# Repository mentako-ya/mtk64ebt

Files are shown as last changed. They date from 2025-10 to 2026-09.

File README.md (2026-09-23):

## 目次

- [mtk64ebt](#mtk64ebt)
    - [トラックボール＆ロータリーエンコーダー付きBluetooth接続自作キーボード](#トラックボールロータリーエンコーダー付きbluetooth接続自作キーボード)
- [バッテリーに関する注意](#バッテリーに関する注意)
- [オンラインストア](#オンラインストア)
- [本体以外に必要なパーツとおすすめ商品](#本体以外に必要なパーツとおすすめ商品)
- [特徴](#特徴)
    - [親指操作トラックボール搭載](#親指操作トラックボール搭載)
        - [ベアリング仕様トラックボールケース対応](#ベアリング仕様トラックボールケース対応)
        - [ベアリング仕様トラックボールケースデータ](#ベアリング仕様トラックボールケースデータ)
    - [Alps alpine製低背エンコーダー搭載](#alps-alpine製低背エンコーダー搭載)
    - [MCU (Seeed Studio XIAO nRF52840)](#mcu-seeed-studio-xiao-nrf52840)
    - [フットスイッチ対応](#フットスイッチ対応)
    - [ZMK Studio 対応](#zmk-studio-対応)
    - [ドングル対応](#ドングル対応)
        - [ドングルにOLEDを取り付けて動作状況を表示できます](#ドングルにoledを取り付けて動作状況を表示できます)
    - [LED表示](#led表示)
        - [セントラル側のLEDで現在のレイヤーが確認できます](#セントラル側のledで現在のレイヤーが確認できます)
        - [LEDレンズ](#ledレンズ)
- [フットスイッチ拡張基板](#フットスイッチ拡張基板)
    - [フットスイッチ無線化モジュール（概要）](#フットスイッチ無線化モジュール概要)
    - [本体基板キットを使用したカスタマイズが可能です](#本体基板キットを使用したカスタマイズが可能です)
- [使用方法](#使用方法)
    - [モジュール間接続](#モジュール間接続)
    - [USB接続](#usb接続)
    - [Bluetooth接続](#bluetooth接続)
    - [ロープロファイル化](#ロープロファイル化)
    - [フットスイッチ拡張キット](#フットスイッチ拡張キット)
    - [フットスイッチ無線化モジュール](#フットスイッチ無線化モジュール)
- [ファームウェア](#ファームウェア)
    - [Rev4 と Rev3 のハードウェア仕様比較](#rev4-と-rev3-のハードウェア仕様比較)
    - [Rev4用ファームウェア一覧](#rev4用ファームウェア一覧)
    - [Rev3用ファームウェア一覧](#rev3用ファームウェア一覧)
    - [ファームウェア書き込み手順](#ファームウェア書き込み手順)
- [ファームウェアのブランチ構成について](#ファームウェアのブランチ構成について)
- [キーマッピング変更](#キーマッピング変更)
    - [ZMK Studioでキーマッピング変更](#zmk-studioでキーマッピング変更)
        - [ブラウザ版 ZMK Studio](#ブラウザ版-zmk-studio)
        - [アプリ版 ZMK Studio](#アプリ版-zmk-studio)
    - [KeymapEditorでキーマッピング変更](#keymapeditorでキーマッピング変更)
- [トラックボール設定](#トラックボール設定)
    - [トラックボール機能のリアルタイム制御 (Rev4 / Rev3)](#トラックボール機能のリアルタイム制御-rev4--rev3)
    - [トラックボール設定変更](#トラックボール設定変更)
        - [自動マウスレイヤー（Layer 6）の設定変更](#自動マウスレイヤーlayer-6の設定変更)
        - [トラックボール感度（CPI）の初期値調整](#トラックボール感度cpiの初期値調整)
- [ケースデータ](#ケースデータ)

# mtk64ebt
<br>

## トラックボール＆ロータリーエンコーダー付きBluetooth接続自作キーボード

mtk64ebtは、親指操作トラックボールとロータリーエンコーダーを搭載した完全ワイヤレス接続分割式キーボードです。

トラックボールとエンコーダーの組み合わせにより、直感的で効率的な操作を実現します。

ワイヤレス接続によりケーブルの煩わしさから解放され、どこへでも快適に持ち運べます。

標準的な６０％キーボード相当のキー数 ＋ フルサイズのキースイッチ ＋ フットスイッチ拡張で、一般的なキーボードからの移行コストを抑え、フルキーボード以上の操作性を実現します。

はんだ付けとケースの組み立てが完了している半完成キットです。キースイッチとキーキャップ、トラックボールを取り付けるだけで、すぐに使用を開始することができます。

## バッテリーに関する注意

> [!CAUTION]
> バッテリー駆動用に[リチウムポリマーバッテリー](https://amzn.asia/d/1ivvf2l)を使用します。
> バッテリーの取り扱いを誤った場合や、製造上の不具合により、破裂や発火の恐れがあります。
> 組み立ての際に動作確認は行っていますが、絶対に安全であることを保証するものではありません。
> バッテリーは使用者の責任において使用してください。
> バッテリー、本体基板、その他構成部品を含め、本製品による事故および不利益損害についての一切の責任は使用者にあり、当方が責任を持つものではありません。

* バッテリー駆動時および、充電時は本体側面のバッテリー駆動用スイッチをONにしてください。
* バッテリー不使用時はバッテリー駆動用スイッチをOFFにしてください。
* 充電中は、発火・破裂しても被害のない場所を選定し、周囲に延焼するものを置かないようにしてください。また充電中はその場を離れることなく常に Li-Po の充電状態を監視してください。
* バッテリーの取り扱いや製造上の不具合について懸念がある場合や、ご自身の責任で使用できない場合、キーボードからバッテリーを取り外してご使用ください。
USB端子からの給電のみでキーボードを使用できます。

## オンラインストア
https://mentako-ya.myshopify.com

## 本体以外に必要なパーツとおすすめ商品

キーキャップMX互換: [CORSAIR PBT DOUBLE-SHOT 交換用カラーキーキャップセット - 日本語108キー, Arctic White - CH-9911040-JP](https://amzn.asia/d/1FShFiO)

キーキャップChocV2: [XVX ロープロファイル PBT キーキャップ](https://amzn.asia/d/7V1A6T4)

キーキャップChocV1: [Chocfox CFX keycap](https://chosfox.com/products/chocfox-cfx-choc-keycaps?bg_ref=3KtshOemT6)

トラックボール: [ぺリックス PERIPRO-303WH 34mm](https://amzn.asia/d/1paUF5C)

USB Type-cケーブル: https://amzn.asia/d/h8pfZIJ

クッションゴム: [ダイソー クッションゴム透明](https://jp.daisonet.com/products/4903409153222)

T5ドライバー(メンテナンス用): [アネックス(ANEX) ドライバー ヘクスローブ T4x50](https://amzn.asia/d/8RFoACS)

## 特徴

### 親指操作トラックボール搭載

キー操作時のトラックボールへの干渉を避けるため、トラックボールの取り付け位置は極力低くオフセットされています

トラックボールケース底面もフラット形状にして、全体の高さを抑えました。

<br>

Rev4ではトラックボールセンサーに**PixArt PAW3222**を採用しました。
Rev3以前のPMW3610と比較して、より低消費電力で高感度と高ポーリングレートを実現しています。

センサー取り付け角度を20度上向きに設定したことで、テンティングなしでも快適にトラックボールを操作することができます。
また、Rev4ではキー操作によるリアルタイムなCPI動的調整（16段階・不揮発性メモリ保存）に対応しています。

<br>

#### トラックボール機能のリアルタイム調整とキーマップ (Rev4)

トラックボールの各種機能（CPI感度調整、Auto Mouse Layer、スクロール反転）は、**レイヤー 1（精密モード）の右手最右列**のキー操作によって、ファームウェアの再書き込みなしでリアルタイムに切り替え・調整が可能です。設定内容は不揮発性メモリ（NVS）に自動保存され、電源オフ後も保持されます。

| 段 | キーコード | 機能 | 説明 |
| :--- | :--- | :--- | :--- |
| **右手最右列 2段目 (ROW 2)** | `&scrl_inv_tog` | スクロール反転切替 | レイヤー3（スクロール）での上下方向（通常 ⇔ 反転）をトグル |
| **右手最右列 3段目 (ROW 3)** | `&aml_tog` | Auto Mouse Layer切替 | ボール操作時の自動マウスレイヤー（レイヤー6）遷移の ON ⇔ OFF |
| **右手最右列 4段目 (ROW 4)** | `&cpi_inc` | CPI 感度UP | トラックボール解像度を1段階上げる（全16段階: 608〜4826 CPI） |
| **右手最右列 最下段 (ROW 5)** | `&cpi_dec` | CPI 感度DOWN | トラックボール解像度を1段階下げる |

※通常マウスモードであるレイヤー 2（MSE）では、誤入力防止のため最右列はすべて透過（`&trans`）となっています。<br>
※OLEDディスプレイ付きドングルでは、現在のCPI数値や機能のON/OFF（下線表示）がリアルタイムに表示されます。詳細な設定方法や仕様については[トラックボール機能のリアルタイム制御 (Rev4)](#トラックボール機能のリアルタイム制御-rev4)を参照してください。

#### ベアリング仕様トラックボールケース対応
トラックボール支持球をベアリングに置き換えるケースデータを公開しています。
ご自身でプリントしてベアリング仕様に変更可能です。



ケースの他に、ベアリング(内径 1.5mm 外径 4mm 幅 2mmのシールドタイプ)とM1.4のネジが必要です。
* ベアリング : [ミネベアミスミ DDL-415ZZ](https://amzn.asia/d/fXq8wOI)
* ネジ : [M1.4-0.3 6mm](https://amzn.asia/d/c3SDJWJ)

#### ベアリング仕様トラックボールケースデータ
[mtk64ebt_rev3_ballBearingCase_RH.3mf](casedata/rev3/mtk64ebt_rev3_ballBearingCase_RH.3mf)<br>[mtk64ebt_rev3_bodyBallBeringBottmn_RH.3mf](casedata/rev3/mtk64ebt_rev3_bodyBallBeringBottmn_RH.3mf)

<br>

### Alps alpine製低背エンコーダー搭載

30クリックの回転操作とプッシュ操作による、直感的な操作が可能です。
一般的なエンコーダーと比較して、クリックトルク、プッシュトルク共に軽い操作感です。

<br>

#### Choc V1、[V2（固定ピンなしモデル）](https://ja.aliexpress.com/item/1005007361067887.html)、およびMX互換キースイッチを全てのキーに取り付けることが可能です

<br>

<br>

親指部分のみをロープロファイル化することも可能です。

追加の親指キースイッチは、操作性を向上させるため、さらに一段低くオフセットされています。

<br>

### MCU (Seeed Studio XIAO nRF52840)

[Seeed Studio XIAO nRF52840](https://jp.seeedstudio.com/Seeed-XIAO-BLE-nRF52840-p-5201.html)を使用しており、無線接続の自作キーボードで課題となる技適対応もクリアしています。

技術基準適合証明番号：[211-220207](https://www.tele.soumu.go.jp/giteki/SearchServlet?pageID=jk01&NUM_TYPE=1&NUM=211-220207)

<br>

光学式センサーに **PAW3222** を採用しており、各接続モード（ESBドングル接続、Bluetooth接続、USB有線接続）におけるポーリングレートの実測値と理論値は以下の通りです。

#### ESB（ドングル）接続時
- **理論値**：最大1000Hz (1ms)
- **実測値**：平均約980Hz / 最大984Hz
- 専用ドングルと超高速ワイヤレスプロトコル **ESB (Enhanced ShockBurst)** を使用することで、完全ワイヤレスでありながら有線接続と同等の超低遅延・高ポーリングレートを実現し、トラックボールの追従性が飛躍的に向上します。

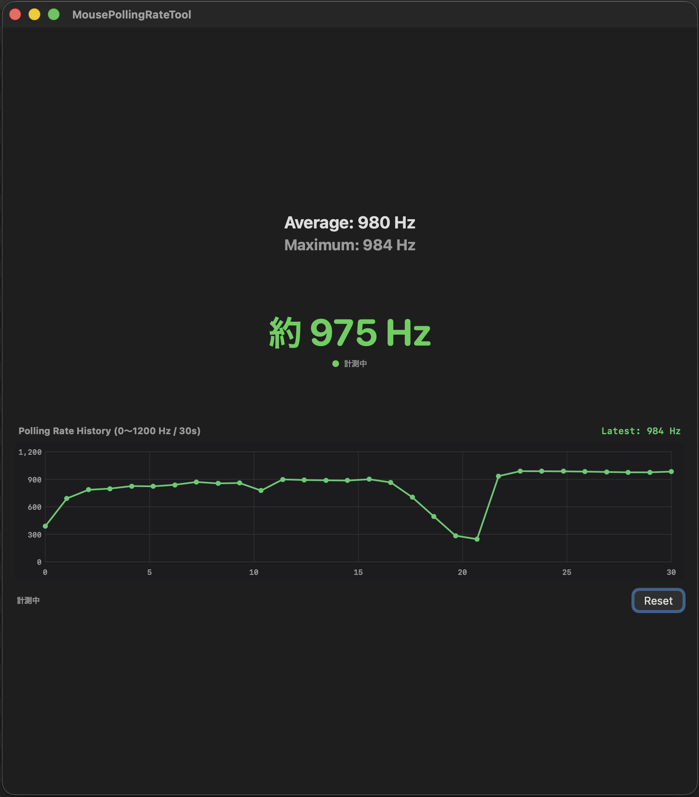
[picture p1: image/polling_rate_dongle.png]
<br>

#### Bluetooth（BLE）接続時
- **理論値**：最大約133Hz（BLE規格の最小接続インターバル 7.5ms 換算）
- **実測値**：平均約109Hz / 最大130Hz
- 一般的なオフィスワークや日常的なPC操作には十分滑らかに使用することが可能です。

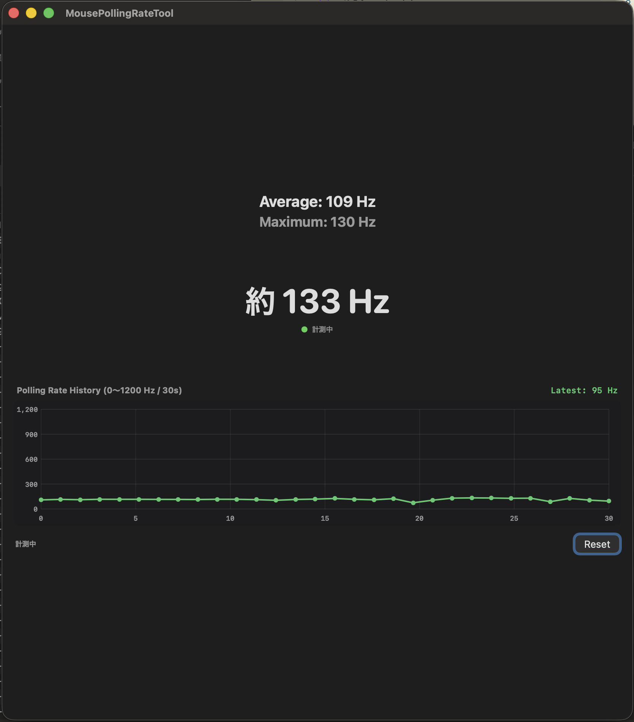
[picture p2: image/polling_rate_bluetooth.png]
<br>

#### USB（有線）接続時
- **理論値**：最大1000Hz (1ms)
- **実測値**：平均約979Hz / 最大984Hz
- ゲーミングマウスと同等の極めて高いポーリングレートを発揮し、高リフレッシュレートモニター環境でも吸い付くような滑らかで精密なトラックボール操作が可能です。
- 有線接続時もトラックボール搭載側（右手側等）のみUSB接続となり、反対側（左手側）は無線接続となるため、PCとの間はUSBケーブル1本のみで配線できます（左右間接続用のTRRSケーブルは使用しません）。

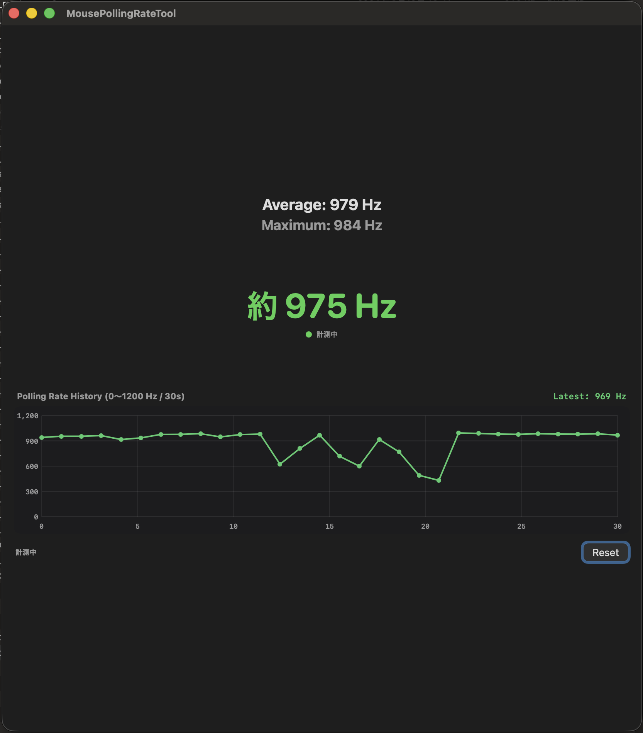
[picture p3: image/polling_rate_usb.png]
<br>

※ ポーリングレートの計測には、macOS向け計測ツール [MousePollingRateTool](https://github.com/mentako-ya/MousePollingRateTool) を使用しています。

### フットスイッチ対応
[市販のUSBフットスイッチ](https://amzn.asia/d/h7wMR24)の基板を付属のフットスイッチ拡張基板に差し替えて、mtk64の拡張無線フットスイッチとして使用可能です。

付属のフットスイッチ無線化モジュールを使用することで、フットスイッチも含めた完全ワイヤレス構成に対応します。

フットスイッチ拡張基板およびフットスイッチ無線化モジュールは、ご自身ではんだ付けと組み立てが必要なキットです。詳細は[フットスイッチ拡張基板](#フットスイッチ拡張基板)および[フットスイッチ無線化モジュール](#フットスイッチ無線化モジュール)を参照してください。

<br>

### ZMK Studio 対応

[ZMK Studio](#zmk-studioでキーマッピング変更)を使用して、キーマッピングを簡単に変更することができます。

<br>

### ESBを使用したドングル対応

[Seeed Studio XIAO BLE](https://jp.seeedstudio.com/Seeed-XIAO-BLE-nRF52840-p-5201.html) を専用ドングルとして使用することで、左右のキーボードは完全無線のまま、Nordic独自の超高速ワイヤレスプロトコル **ESB (Enhanced ShockBurst)** による超低遅延通信を行います。

完全ワイヤレスでありながら、USB直接接続と同等の **1000Hz (1ms)** に近いポーリングレートを実現し、トラックボールの追従性が飛躍的に向上します。（※Rev3ではBLEドングルによる約110~220Hz動作）

- **理論値**：1000Hz (1ms)
- **実測値**：平均約980Hz / 最大984Hz

<br>

<br>

#### ドングルにOLEDを取り付けて動作状況を表示できます

[0.96インチ 128×64ドットOLED(SSD1306)](https://akizukidenshi.com/catalog/g/g112031/)のGND,VCC,SCL,SDA を[XiaoBLEの GND,3v3,D10,D9 ](https://files.seeedstudio.com/wiki/XIAO-BLE/pinout2.png)に結線してください。

OLEDのピンヘッダ位置とXiaoBLEの端子位置を合わせてあるので、配線なしでピンヘッダで直付も可能です。

注：リセットスイッチは押せないので、リセットする際はXiaoBLE背面のRST端子とGND端子を短絡してください。

<br>
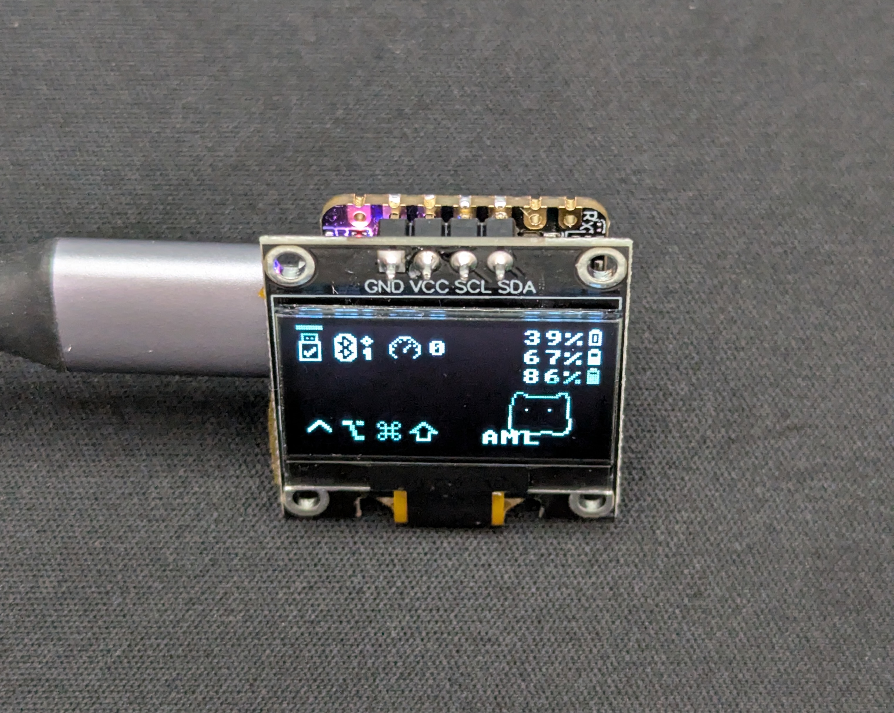
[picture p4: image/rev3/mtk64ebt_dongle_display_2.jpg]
<br>

##### OLEDディスプレイ画面の表示内容

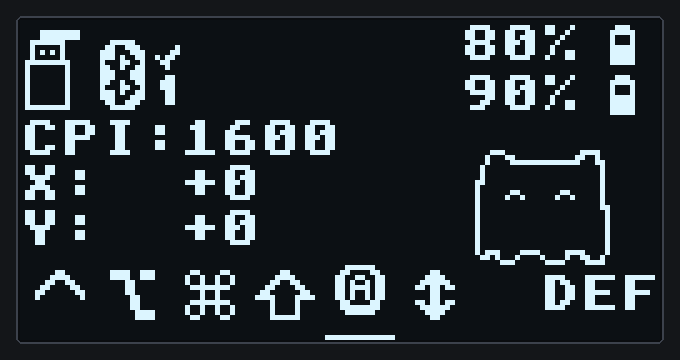
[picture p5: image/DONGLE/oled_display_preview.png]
<br>

| 領域 / アイコン | 表示内容 | 説明 |
| :--- | :--- | :--- |
| **左上 (出力状態)** | 🔌 USB / 📶 Bluetooth (1〜5) | 接続モード、選択中のBTプロファイル番号、接続状態（✓）を表示。現在選択されている出力の上部にバーが表示されます。 |
| **右上 (バッテリー)** | 🔋 L: 80% / R: 90% | 左右ペリフェラルのバッテリー残量（%）と電池アイコンをリアルタイム表示。 |
| **左中 (トラックボール)** | `CPI:1600`<br>`X:  +0`<br>`Y:  +0` | 現在のCPI解像度およびトラックボールのX/Y累積移動量をリアルタイム表示。 |
| **右中 (マスコット)** | めんたこ | 打鍵速度に連動してアニメーション。 |
| **左下 (モディファイア)** | `^` `⌥` `⌘` `⇧` | 現在押下中のモディファイアキー（Ctrl, Opt, Cmd, Shift）に下線（`_`）が表示されます。 |
| **中下 (ポインティング機能)** | 🎱 (A) Automouse<br>↕️ Scroll反転 | **Automouse**: 有効時に下線（`_`）が表示されます。<br>**Scroll反転**: スクロール反転有効時に下線（`_`）が表示されます。 |
| **右下 (レイヤー)** | `DEF`, `SNP`, `MSE` ... | 現在アクティブな最上位レイヤー名（`DEF`, `SNP`, `MSE`, `SCR`, `L4`, `L5`, `AML` 等）が右端に表示されます。 |

### LED表示

#### セントラル側のLEDで現在のレイヤーが確認できます
```
レイヤー０ ⚫️Black（無点灯）
レイヤー１ 🟣Magenta トラックボール精密モード
レイヤー２ 🔵Cyan    トラックボールモード
レイヤー３ 🟡Yellow  スクロールモード
レイヤー４ 🟢Green
レイヤー５ 🔵Blue
レイヤー６ ⚪️White   自動マウスレイヤー
```

#### LEDレンズ
インジケーターLEDにレンズを装着することで高い視認性を実現し、バッテリー残量や接続状態、レイヤー切り替えがわかりやすくなりました。

<br>

## フットスイッチ拡張基板

[市販のUSBフットスイッチ](https://amzn.asia/d/h7wMR24)の基板を付属のフットスイッチ拡張基板に差し替えてmtk64のフットスイッチとして使用可能です。

フットスイッチはmtk64の一部として機能するので、レイヤー切り替えやカスタムキーなどキーボード固有の操作が可能です。


<br>
<br>  

### フットスイッチ無線化モジュール（概要）
付属のフットスイッチ無線化モジュールにより完全無線接続のフットスイッチが完成します。

<br>

#### 本体基板キットを使用したカスタマイズが可能です

作例：左ボール 右エンコーダ ドングル OLED
（ファームウェア、ケースデータは各セクションを参照）
<br>

## 使用方法

## モジュール間接続

mtk64ebtは、右手モジュールがセントラルモジュールとして動作します。左手モジュールとフットスイッチは右手モジュールに自動的にペアリングされます。

各モジュールのLEDの色と接続状態については、[こちら](https://github.com/mentako-ya/zmk-rgbled-widget/blob/main/README.md)を参照してください。LEDの色によって接続状態が視覚的に確認できるため、接続状況を簡単に把握することができます。

各モジュール間の接続ができない場合は、ファームウェア書き込み手順に従って、各モジュールの接続をリセットしてください。接続の問題を解決して再度正常に動作させることができます。

## USB接続

右手モジュール（セントラルモジュール）は、PCとUSBで有線接続可能です。USB接続時、セントラルモジュールはPCとの通信を行いながら、充電も行います。

左手モジュールやフットスイッチ無線化モジュール（ペリフェラルモジュール）は、USB接続時に充電のみを行います。これらのモジュールは、操作に必要な通信をすべて無線接続でセントラルモジュールと行います。

> [!CAUTION]
> Rev.2以前の右手モジュールと左手モジュールにある3.5mmジャックはフットスイッチ拡張キットを有線接続するための端子です。
> 左右間の有線接続用ではありません。
> 故障の原因となるので、左右のキーボードをTRSケーブルで接続しないでください。

## Bluetooth接続

レイヤー1の「ESC」「1」〜「5」キーを使用して、最大６か所のBluetooth接続先を切り替えることができます。



接続後にキーボードが動作しない場合は、リセットボタンを押下して再接続を試みてください。

## ロープロファイル化

Choc V1、V2を使用する場合、トッププレート固定用ネジ(T5 8mm)を外してトッププレートを取り除き、付属の6mmねじに付け替えます。ネジの交換にはT5ドライバーを使用します。

## フットスイッチ拡張キット

フットスイッチ拡張キットはご自身で市販のフットスイッチにキットの基板を組み込み、はんだ付けをするキットです。

フットスイッチの作成方法は[こちらのビルドムービー](https://youtu.be/NavGAliALVc?si=JpO-xi0RZznjVi4-)をご覧ください。

フットスイッチの接続は3.5mm４極のTRRS端子を使用しますが、有線でフットスイッチを接続する場合（30cm以上のケーブル長が必要な場合）、市販のTRRSケーブルは線が細すぎるので使用できません。

TRRS端子とAWG28~26以上（番号が小さい方が太いです）のケーブルを組み合わせて自作します。

[遊舎工房自作ケーブルキット](https://shop.yushakobo.jp/products/self-made-cable?_pos=1&_sid=79305908f&_ss=r&variant=39623339737249)

[AWG26 4Cシールドケーブル](https://shop.oyaide.com/products/mogami_2893.html)

配線の色は使用するケーブルのメーカーによって異なります。
４極プラグの端子側とフットスイッチ拡張キット側の結線は下図を参照してください。

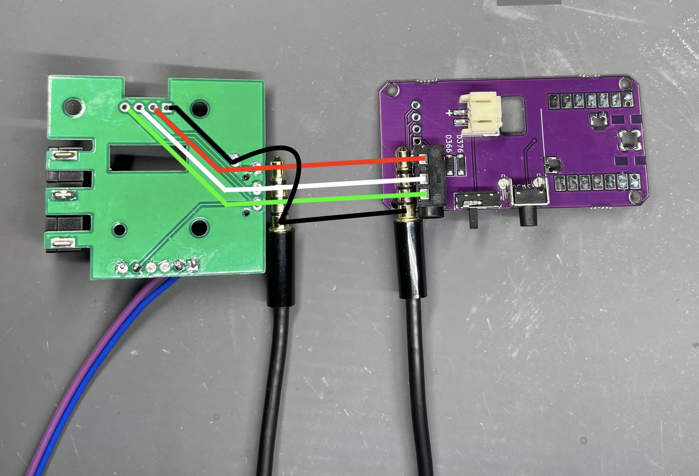
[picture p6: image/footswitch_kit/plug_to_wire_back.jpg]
<br>
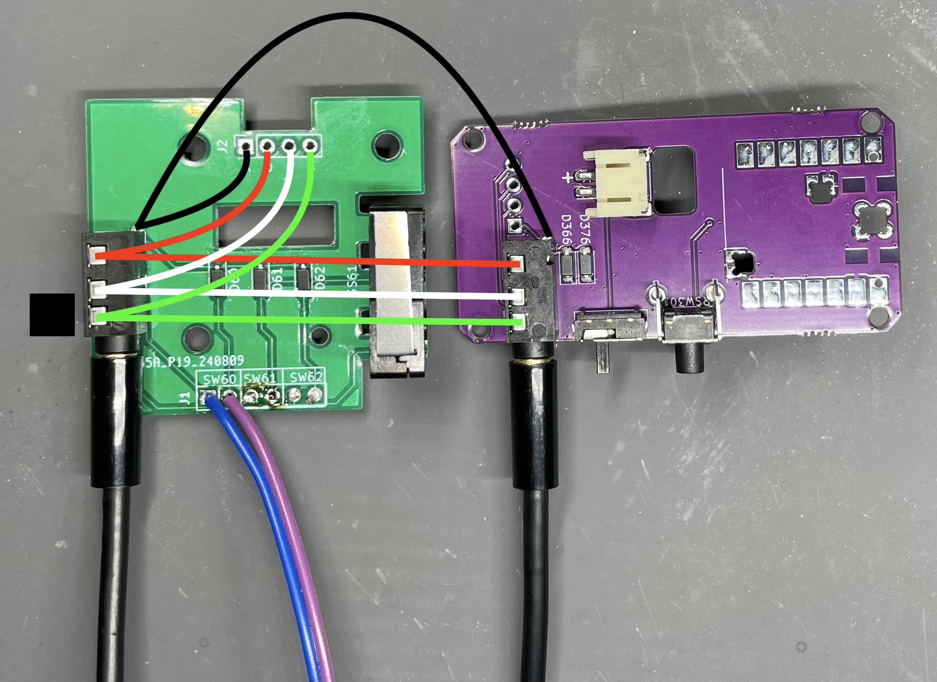
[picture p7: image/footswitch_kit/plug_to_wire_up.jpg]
<br>
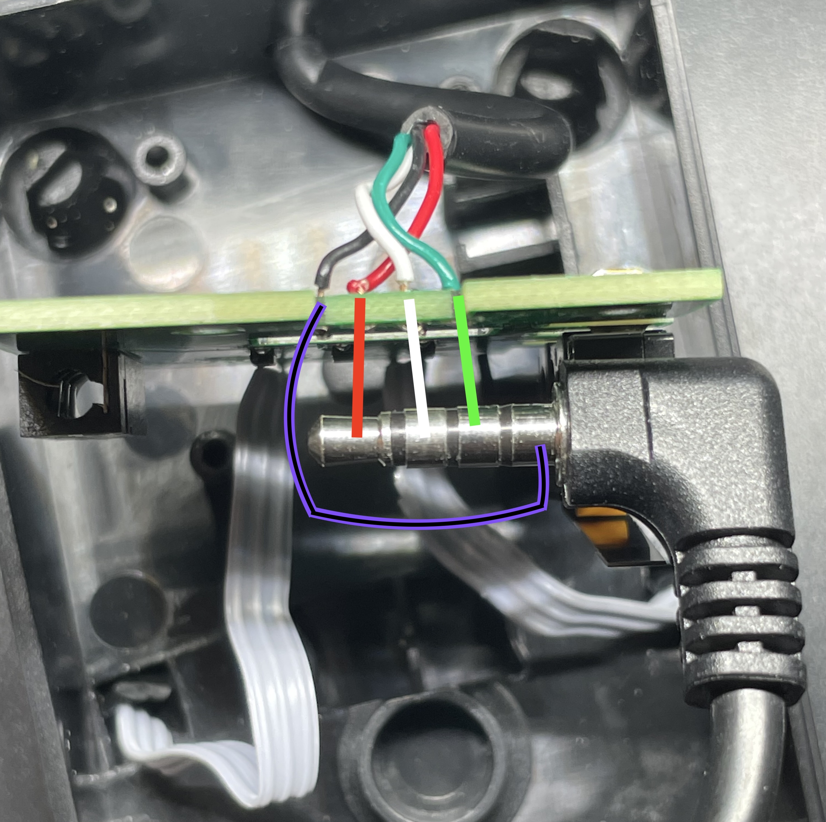
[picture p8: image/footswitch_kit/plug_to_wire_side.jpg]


## フットスイッチ無線化モジュール

フットスイッチ無線化モジュールを使用する場合、[Seeed Studio XIAO nRF52840](https://jp.seeedstudio.com/Seeed-XIAO-BLE-nRF52840-p-5201.html)、[リチウムポリマーバッテリー 902030 PH2.0プラグ付き](https://ja.aliexpress.com/item/1005006838195720.html)、[ケース（ご自身で3Dプリント）](casedata/rev3/mtk64ebt_rev3_footmodule_case.3mf) が別途必要です。

フットスイッチ拡張キットをフットスイッチ無線化モジュールに接続して、mtk64ebtに無線接続します。

フットスイッチキットとフットスイッチ無線化モジュールを接続する場合、フットスイッチ側の線を極力短くするのがオススメです。

写真は[こちらの４極3.5mm端子付きケーブル](https://www.digikey.jp/ja/products/detail/assmann-wsw-components/A-AV-02-45-28-183-S2/16906692)を15cmにカットして使用しています。


 

## ファームウェア

### Rev4 と Rev3 のハードウェア仕様比較

Rev4 と Rev3 では、搭載されているトラックボールセンサーの型番および CPI の調整ステップ数が異なりますが、ファームウェア機能としてはどちらも最新の仕様（ESB 1000Hz 超低遅延通信、リアルタイム設定制御、ZMK Studio 完全対応、ドングル OLED 連携）を共通してサポートしています。

| 比較項目 | Rev4（最新） | Rev3 |
| :--- | :--- | :--- |
| **トラックボールセンサー** | **PixArt PAW3222** | **PixArt PMW3610** |
| **CPI 調整範囲** | **16段階**（608 〜 4826 CPI） | **15段階**（200 〜 3200 CPI） |
| **PC / 親機間通信** | **Bluetooth (133Hz BLE Split)** または<br>**Nordic ESB (1000Hz 超低遅延)** | **Bluetooth (133Hz BLE Split)** または<br>**Nordic ESB (250Hz 超低遅延)** |
| **リアルタイム設定制御** | CPI感度調整 / Auto Mouse Layer / スクロール反転 | CPI感度調整 / Auto Mouse Layer / スクロール反転 |
| **設定の不揮発性保存 (NVS)** | 対応（電源OFF・電池交換後も保持） | 対応（電源OFF・電池交換後も保持） |
| **ZMK Studio** | 完全対応（リアルタイムキーマップ変更） | 完全対応（リアルタイムキーマップ変更） |
| **ドングル OLED 連携** | CPI値 / AML状態 / スクロール反転 / 電池残量 | CPI値 / AML状態 / スクロール反転 / 電池残量 |

> [!IMPORTANT]
> 搭載されているトラックボールセンサー（PAW3222 と PMW3610）のドライバが異なるため、**Rev4 と Rev3 でファームウェアのバイナリ互換性はありません**。
> お手持ちのキーボードのリビジョンに合致したファームウェアおよび対応ブランチをご使用ください。

---

### Rev4用ファームウェア一覧

本リポジトリでは、接続方式に応じてファームウェアを分離・最適化して提供しています。

#### 1. Bluetooth 接続（BLE Split / ドングル不要）構成【デフォルトブランチ: [`right_left_rev4`](https://github.com/mentako-ya/zmk-config-mtk64/tree/right_left_rev4)】

ドングルを使わず、右手（Central）と PC を Bluetooth でペアリングし、左手・フットスイッチとも安定した BLE Split 通信を行う標準構成です。
本リポジトリの [`firmware/rev4/`](firmware/rev4/) ディレクトリより最新版をダウンロードいただけます。

| No | 構成名 | パッケージ名 (ZIP) | 含まれるファームウェア (.uf2) |
| :--- | :--- | :--- | :--- |
| 1 | **左右構成（右ボール/左エンコーダー）** | [mtk64ebt_Right_Left.zip](firmware/rev4/mtk64ebt_Right_Left.zip) | `mtk64_R.uf2`, `mtk64_L.uf2`, `settings_reset.uf2` |
| 2 | **左右構成（左ボール/右エンコーダー）** | [mtk64ebt_Right_Left_leftball.zip](firmware/rev4/mtk64ebt_Right_Left_leftball.zip) | `mtk64_R_leftball.uf2`, `mtk64_L_leftball.uf2`, `settings_reset.uf2` |
| 3 | **左右＋フットスイッチ（右ボール/左エンコーダー）** | [mtk64ebt_Right_Left_Foot.zip](firmware/rev4/mtk64ebt_Right_Left_Foot.zip) | `mtk64_R.uf2`, `mtk64_L.uf2`, `mtk64_FOOT.uf2`, `settings_reset.uf2` |
| 4 | **左右＋フットスイッチ（左ボール/右エンコーダー）** | [mtk64ebt_Right_Left_Foot_leftball.zip](firmware/rev4/mtk64ebt_Right_Left_Foot_leftball.zip) | `mtk64_R_leftball.uf2`, `mtk64_L_leftball.uf2`, `mtk64_FOOT.uf2`, `settings_reset.uf2` |

> [!TIP]
> 直接接続用のファームウェアビルドやカスタマイズは、[zmk-config-mtk64](https://github.com/mentako-ya/zmk-config-mtk64) のデフォルトブランチ **[`right_left_rev4`](https://github.com/mentako-ya/zmk-config-mtk64/tree/right_left_rev4)** をご使用ください。

---

#### 2. ドングル接続（1000Hz ESB超低遅延）構成【ブランチ: [`right_left_dongle_rev4`](https://github.com/mentako-ya/zmk-config-mtk64/tree/right_left_dongle_rev4)】

専用 USB ドングルを Central 親機とし、左右手・フットスイッチを 1000Hz ポーリングの超低遅延 Nordic ESB プロトコルで通信させるハイパフォーマンス構成です。
本リポジトリの [`firmware/rev4/`](firmware/rev4/) ディレクトリ、または [zmk-config-mtk64 Releases](https://github.com/mentako-ya/zmk-config-mtk64/releases) よりダウンロードいただけます。

| No | 構成名 | パッケージ名 (ZIP) | 含まれるファームウェア (.uf2) |
| :--- | :--- | :--- | :--- |
| 1 | **左右＋ドングルOLED＋フット（右ボール/左エンコーダー）** | [mtk64ebt_Right_Left_Dongle_disp_foot.zip](firmware/rev4/mtk64ebt_Right_Left_Dongle_disp_foot.zip) | `mtk64_DONGLE_display.uf2`, `mtk64_R_dongle.uf2`, `mtk64_L_dongle.uf2`, `mtk64_FOOT.uf2`, `settings_reset.uf2` |
| 2 | **左右＋ドングルOLED（右ボール/左エンコーダー）** | [mtk64ebt_Right_Left_Dongle_display.zip](firmware/rev4/mtk64ebt_Right_Left_Dongle_display.zip) | `mtk64_DONGLE_display.uf2`, `mtk64_R_dongle.uf2`, `mtk64_L_dongle.uf2`, `settings_reset.uf2` |
| 3 | **左右＋ドングルOLED（左ボール/右エンコーダー）** | [mtk64ebt_Right_Left_Dongle_disp_leftball.zip](firmware/rev4/mtk64ebt_Right_Left_Dongle_disp_leftball.zip) | `mtk64_DONGLE_display.uf2`, `mtk64_R_leftball.uf2`, `mtk64_L_leftball.uf2`, `settings_reset.uf2` |
| 4 | **左右＋ドングル（画面なし）＋フット（右ボール/左エンコーダー）** | [mtk64ebt_Right_Left_Dongle_foot.zip](firmware/rev4/mtk64ebt_Right_Left_Dongle_foot.zip) | `mtk64_DONGLE.uf2`, `mtk64_R_dongle.uf2`, `mtk64_L_dongle.uf2`, `mtk64_FOOT.uf2`, `settings_reset.uf2` |
| 5 | **左右＋ドングル（画面なし）（右ボール/左エンコーダー）** | [mtk64ebt_Right_Left_Dongle.zip](firmware/rev4/mtk64ebt_Right_Left_Dongle.zip) | `mtk64_DONGLE.uf2`, `mtk64_R_dongle.uf2`, `mtk64_L_dongle.uf2`, `settings_reset.uf2` |

> [!TIP]
> ドングル構成のファームウェアビルドやカスタマイズは、[zmk-config-mtk64](https://github.com/mentako-ya/zmk-config-mtk64) の **[`right_left_dongle_rev4`](https://github.com/mentako-ya/zmk-config-mtk64/tree/right_left_dongle_rev4)** ブランチをご使用ください。

---

### Rev3用ファームウェア一覧

Rev3 用のファームウェアも Rev4 と同様にブランチが一本化され、直接接続用（4構成）とドングル接続用（5構成）の計 9 種類のパッケージを提供しています。
本リポジトリの [`firmware/rev3/`](firmware/rev3/) ディレクトリより最新版をダウンロードいただけます。

#### 1. Bluetooth 接続（BLE Split / ドングル不要）構成【ブランチ: [`right_left_rev3`](https://github.com/mentako-ya/zmk-config-mtk64/tree/right_left_rev3)】

ドングルを使わず、右手（Central）と PC を Bluetooth でペアリングし、左手・フットスイッチとも安定した BLE Split 通信を行う標準構成です。

| No | 構成名 | パッケージ名 (ZIP) | 含まれるファームウェア (.uf2) |
| :--- | :--- | :--- | :--- |
| 1 | **左右構成（右ボール/左エンコーダー）** | [mtk64ebt_Right_Left.zip](firmware/rev3/mtk64ebt_Right_Left.zip) | `mtk64_R.uf2`, `mtk64_L.uf2`, `settings_reset.uf2` |
| 2 | **左右構成（左ボール/右エンコーダー）** | [mtk64ebt_Right_Left_leftball.zip](firmware/rev3/mtk64ebt_Right_Left_leftball.zip) | `mtk64_R_leftball.uf2`, `mtk64_L_leftball.uf2`, `settings_reset.uf2` |
| 3 | **左右＋フットスイッチ（右ボール/左エンコーダー）** | [mtk64ebt_Right_Left_Foot.zip](firmware/rev3/mtk64ebt_Right_Left_Foot.zip) | `mtk64_R.uf2`, `mtk64_L.uf2`, `mtk64_FOOT.uf2`, `settings_reset.uf2` |
| 4 | **左右＋フットスイッチ（左ボール/右エンコーダー）** | [mtk64ebt_Right_Left_Foot_leftball.zip](firmware/rev3/mtk64ebt_Right_Left_Foot_leftball.zip) | `mtk64_R_leftball.uf2`, `mtk64_L_leftball.uf2`, `mtk64_FOOT.uf2`, `settings_reset.uf2` |

> [!TIP]
> Rev3 直接接続用のファームウェアビルドやカスタマイズは、[zmk-config-mtk64](https://github.com/mentako-ya/zmk-config-mtk64) の **[`right_left_rev3`](https://github.com/mentako-ya/zmk-config-mtk64/tree/right_left_rev3)** ブランチをご使用ください。

---

#### 2. ドングル接続（250Hz ESB超低遅延）構成【ブランチ: [`right_left_dongle_rev3`](https://github.com/mentako-ya/zmk-config-mtk64/tree/right_left_dongle_rev3)】

専用 USB ドングルを Central 親機とし、左右手・フットスイッチを 250Hz ポーリングの超低遅延 Nordic ESB プロトコルで通信させるハイパフォーマンス構成です。

| No | 構成名 | パッケージ名 (ZIP) | 含まれるファームウェア (.uf2) |
| :--- | :--- | :--- | :--- |
| 1 | **左右＋ドングルOLED＋フット（右ボール/左エンコーダー）** | [mtk64ebt_Right_Left_Dongle_disp_foot.zip](firmware/rev3/mtk64ebt_Right_Left_Dongle_disp_foot.zip) | `mtk64_DONGLE_display.uf2`, `mtk64_R_dongle.uf2`, `mtk64_L_dongle.uf2`, `mtk64_FOOT.uf2`, `settings_reset.uf2` |
| 2 | **左右＋ドングルOLED（右ボール/左エンコーダー）** | [mtk64ebt_Right_Left_Dongle_display.zip](firmware/rev3/mtk64ebt_Right_Left_Dongle_display.zip) | `mtk64_DONGLE_display.uf2`, `mtk64_R_dongle.uf2`, `mtk64_L_dongle.uf2`, `settings_reset.uf2` |
| 3 | **左右＋ドングルOLED（左ボール/右エンコーダー）** | [mtk64ebt_Right_Left_Dongle_disp_leftball.zip](firmware/rev3/mtk64ebt_Right_Left_Dongle_disp_leftball.zip) | `mtk64_DONGLE_display.uf2`, `mtk64_R_leftball.uf2`, `mtk64_L_leftball.uf2`, `settings_reset.uf2` |
| 4 | **左右＋ドングル（画面なし）＋フット（右ボール/左エンコーダー）** | [mtk64ebt_Right_Left_Dongle_foot.zip](firmware/rev3/mtk64ebt_Right_Left_Dongle_foot.zip) | `mtk64_DONGLE.uf2`, `mtk64_R_dongle.uf2`, `mtk64_L_dongle.uf2`, `mtk64_FOOT.uf2`, `settings_reset.uf2` |
| 5 | **左右＋ドングル（画面なし）（右ボール/左エンコーダー）** | [mtk64ebt_Right_Left_Dongle.zip](firmware/rev3/mtk64ebt_Right_Left_Dongle.zip) | `mtk64_DONGLE.uf2`, `mtk64_R_dongle.uf2`, `mtk64_L_dongle.uf2`, `settings_reset.uf2` |

> [!TIP]
> Rev3 ドングル構成のファームウェアビルドやカスタマイズは、[zmk-config-mtk64](https://github.com/mentako-ya/zmk-config-mtk64) の **[`right_left_dongle_rev3`](https://github.com/mentako-ya/zmk-config-mtk64/tree/right_left_dongle_rev3)** ブランチをご使用ください。

### ファームウェア書き込み手順

1. 右手キーボード、左手キーボード、フットスイッチ拡張モジュールのバッテリー駆動スイッチをOFFにする

> [!IMPORTANT]
> バッテリーから給電された状態ではファームウェア書き込み後のリセットが正しく行われません。

1. **右手キーボード書き込み**:
   * 右手キーボードをPCにUSB接続して、基板上のリセットボタンを短く2回押下（ダブルクリック）。
   * 認識されたリムーバブルディスク ”XIAO-SENSE" に `settings_reset.uf2` をドラッグ＆ドロップ（自動再起動）。
   * 再度リセットボタンを短く2回押下し、”XIAO-SENSE" に対応する右手ファームウェア（標準構成: 直接接続なら `mtk64_R.uf2` / ドングル構成なら `mtk64_R_dongle.uf2`、左ボール構成: `mtk64_R_leftball.uf2`）をドロップ。

1. **左手キーボード書き込み**:
   * 左手キーボードをPCにUSB接続して、リセットボタンを短く2回押下。
   * ”XIAO-SENSE" に `settings_reset.uf2` をドロップ。
   * 再度リセットボタンを短く2回押下し、対応する左手用ファームウェア（標準構成: 直接接続なら `mtk64_L.uf2` / ドングル構成なら `mtk64_L_dongle.uf2`、左ボール構成: `mtk64_L_leftball.uf2`）をドロップ。

1. **ドングル / フットスイッチ書き込み（使用時）**:
   * **ドングルモジュール**: PCにUSB接続してリセットボタンを短く2回押下し、`mtk64_DONGLE_display.uf2`（画面なしは `mtk64_DONGLE.uf2`）をドロップ。
   * **フットスイッチ無線化モジュール**: PCにUSB接続してリセットボタンを短く2回押下し、`settings_reset.uf2` を書き込んだ後、対応するファームウェア（`mtk64_FOOT.uf2`）をドロップ。

1. **接続確認**:
   * 右手キーボード（またはドングル）をPCにUSB接続し、左手キーボードとフットスイッチ拡張モジュールはバッテリー駆動スイッチをONにして給電します。
   * 各モジュールのリセットスイッチを1回押下し、USB端子横のLEDで接続状態を確認します。
   * 右手（またはドングル）のLED: PCとの接続状態を表す（接続中🔵、オープン/アドバタイズ🟡、切断中🔴）。
   * 左手・フットスイッチのLED: セントラルとのペアリング状態を表す（接続中🔵、切断中🔴）。

LEDの色と接続状態についての詳細は [zmk-rgbled-widget](https://github.com/mentako-ya/zmk-rgbled-widget/blob/main/README.md) を参照してください。

## ファームウェアのブランチ構成について

[zmk-config-mtk64](https://github.com/mentako-ya/zmk-config-mtk64) リポジトリでは、ハードウェアリビジョン（Rev4 / Rev3）および接続方式（直接接続 / ドングル接続）に応じてブランチを最適化・提供しています。

### ブランチ一覧マトリクス

| ハードウェア | 接続方式 | ブランチ名 | 説明 |
| :--- | :--- | :--- | :--- |
| **Rev4（PAW3222）** | **Bluetooth 直接接続** | [`right_left_rev4`](https://github.com/mentako-ya/zmk-config-mtk64/tree/right_left_rev4)（デフォルト） | ドングル不要で PC と左右を Bluetooth ペアリングする標準構成（全4パッケージ一括ビルド） |
| **Rev4（PAW3222）** | **1000Hz ドングル接続** | [`right_left_dongle_rev4`](https://github.com/mentako-ya/zmk-config-mtk64/tree/right_left_dongle_rev4) | 専用 USB ドングル＋Nordic ESB 超低遅延（1000Hz）構成（全5パッケージ一括ビルド） |
| **Rev3（PMW3610）** | **Bluetooth 直接接続** | [`right_left_rev3`](https://github.com/mentako-ya/zmk-config-mtk64/tree/right_left_rev3) | ドングル不要で PC と左右を Bluetooth ペアリングする標準構成（全4パッケージ一括ビルド） |
| **Rev3（PMW3610）** | **1000Hz ドングル接続** | [`right_left_dongle_rev3`](https://github.com/mentako-ya/zmk-config-mtk64/tree/right_left_dongle_rev3) | 専用 USB ドングル＋Nordic ESB 超低遅延（1000Hz）構成（全5パッケージ一括ビルド） |

### Rev3 ブランチ構成の大幅アップデート（ハードウェア構成別ブランチの集約・一本化）

従来、Rev3 のファームウェアリポジトリはハードウェア構成ごと（直接接続通常、直接接続フット、ドングル通常、ドングルOLED、ドングルOLEDフット、左ボールなど）に 8 つ以上の個別ブランチに分かれており、キーマップを変更する際も目的の構成ブランチを個別に探して編集する必要がありました。

今回のファームウェア更新に伴い、Rev4 と同様に **「Bluetooth 直接接続（[`right_left_rev3`](https://github.com/mentako-ya/zmk-config-mtk64/tree/right_left_rev3)）」** と **「ドングル接続（[`right_left_dongle_rev3`](https://github.com/mentako-ya/zmk-config-mtk64/tree/right_left_dongle_rev3)）」** の **2 つの統合ブランチへ完全集約・一本化** されました。

* **マトリクス一括ビルドの導入**:
  GitHub Actions のマトリクスビルドを採用したことで、1 つのブランチからすべてのハードウェアバリエーション（標準、左ボール、フットスイッチ、OLEDあり/なし等）が一括で自動ビルドされます。
* **キーマップ変更・メンテナンスの劇的な簡素化**:
  キーマップ（`config/mtk64.keymap`）を 1 箇所編集してコミットするだけで、その接続方式に対応する全構成のファームウェアが一括で再生成されます。構成ごとに別ブランチへ切り替えて同じキーマップ変更を繰り返す必要がなくなりました。
* **最新機能の全面バックポート**:
  Rev3 でも Rev4 と同等の機能（PMW3610 の 15 段階 CPI リアルタイム制御、スクロール上下反転、Auto Mouse Layer、NVS 不揮発性保存、ZMK Studio 完全対応、ドングル OLED 連携）が利用可能です。

## キーマッピング変更

### ZMK Studioでキーマッピング変更

ZMK Studioを使用することで、ファームウェア書き換えなしでキーマッピングを簡単に変更することができます。

<br>

#### ブラウザ版 ZMK Studio
ブラウザ版のZMK Studioを使用する場合、右手側のモジュールをUSB接続し、[こちら](https://zmk.studio/)にアクセスしてください。

#### アプリ版 ZMK Studio
アプリ版のZMK Studioは、[こちら](https://zmk.studio/download)からダウンロードできます。アプリ版では、無線接続のままキーマップの変更が可能です。ケーブルを接続する手間を省き、より柔軟にキーマッピングを調整することができます。

### KeymapEditorでキーマッピング変更

キースイッチのマッピングだけでなく、エンコーダーのキーマッピング、マクロやコンボの追加、編集をしたい場合、[キーマップエディター](https://nickcoutsos.github.io/keymap-editor/)を使用して変更可能です。

キーマップエディターでマッピングを変更するためには、ご自身のgithubアカウントでmtk64ebtのファームウェアリポジトリをフォークして、キーマップエディターで編集する必要があります。

操作はブラウザだけで完結するので、特別なツールは不要です。

1. https://github.com/mentako-ya/zmk-config-mtk64 を開いて画面右上の「Fork」をクリック



2. 「Create fork」のボタンをクリックしてフォークを作成します

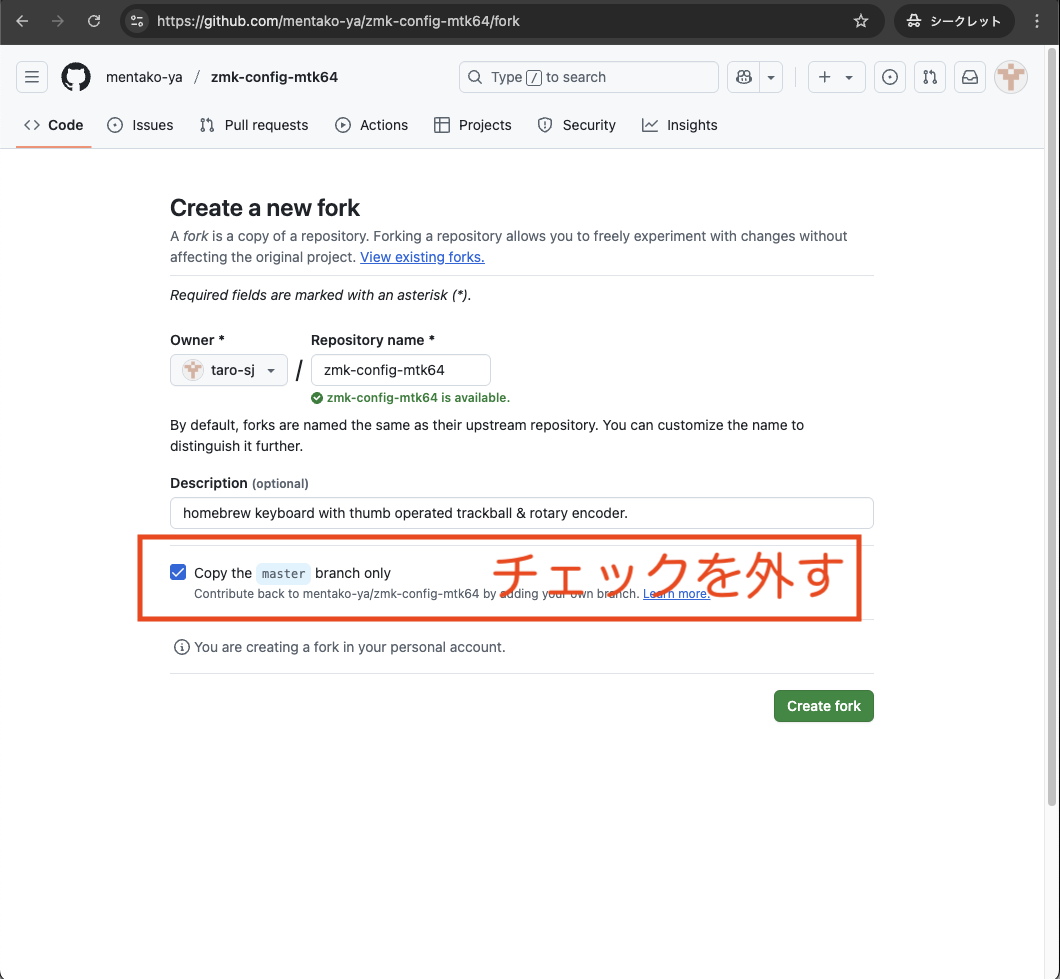
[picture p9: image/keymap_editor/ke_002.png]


3. ご自身のgitHubアカウントにzmk-config-mtk64のフォークが作成されます



4. https://nickcoutsos.github.io/keymap-editor/ を開いて「GitHub」のアイコンをクリック



5. 先ほどzmk-config-mtk64のフォークを作成したGitHubのアカウントで認証



6. 「Authorize Keymap Editor」をクリック



7. 「Add Repository」をクリック



8. 「Only select repositories」のラジオボタンを選択 -> 「Select repositories」のプルダウンから「zmk-config-mtk64」を選択 -> 「Install」をクリック



9. キーマップエディター画面でフォークしたリポジトリと作業ブランチを選択します。
   * **Rev4 をお使いの場合**:
     * 直接接続（ドングル不要）: [`right_left_rev4`](https://github.com/mentako-ya/zmk-config-mtk64/tree/right_left_rev4)
     * ドングル接続（1000Hz ESB）: [`right_left_dongle_rev4`](https://github.com/mentako-ya/zmk-config-mtk64/tree/right_left_dongle_rev4)
   * **Rev3 をお使いの場合**:
     * 直接接続（ドングル不要）: [`right_left_rev3`](https://github.com/mentako-ya/zmk-config-mtk64/tree/right_left_rev3)
     * ドングル接続（250Hz ESB）: [`right_left_dongle_rev3`](https://github.com/mentako-ya/zmk-config-mtk64/tree/right_left_dongle_rev3)



10. キーをクリックして編集　例として、エンコーダーのキーマップを変更



11. saveボタンを押して変更したキーマップをコミット



12. フォークした自分のzmk-config-mtk64リポジトリをブラウザで開く -> Actionsメニュー -> .github/workflows/build.yml選択 -> 「Run workflow」クリック -> Run workflow
（またはローカルでコミットして `git push origin <作業ブランチ名>` すると自動的にビルドが開始されます）



13. 実行完了後、フォーク先リポジトリの「Releases」（`latest-main`）または Actions 実行画面最下部の「Artifacts」から、ご自身の構成に対応するファームウェア ZIP をダウンロードします。

14. [ファームウェア書き込み手順](#ファームウェア書き込み手順)に従って書き込みます。

#### 左ボール右エンコーダー構成のキーマップ対応について
* ドングル構成用の **[`right_left_dongle_rev4`](https://github.com/mentako-ya/zmk-config-mtk64/tree/right_left_dongle_rev4)** ブランチおよび **[`right_left_dongle_rev3`](https://github.com/mentako-ya/zmk-config-mtk64/tree/right_left_dongle_rev3)** ブランチでは、全ドングル構成（通常ドングル、左ボール構成、フットスイッチ構成など）が一括ビルドされます。
* `config/mtk64.keymap` の変更は、通常の右手ボール構成だけでなく左ボール構成（`mtk64ebt_Right_Left_Dongle_disp_leftball.zip` 等）にも自動的に反映されます。
* 左ボール構成を使用する場合、左手でトラックボールを操作しながら右手でクリック操作を行えるよう標準マッピング（レイヤー1・2・6にマウスボタン配置）されています。左手側にクリックキーを配置したい場合も、`mtk64.keymap` の左手側キーにお好みのマウスキー（`&mkp MB1` 等）を割り当てるだけで自由に変更できます。

## トラックボール設定

各レイヤーごとの動作について説明します。

* **Layer 0 (Base / DEF)** は通常レイヤーです。これはデフォルトのレイヤーで、通常のキーボード操作が行われます。
* **Layer 1 (Snipe / SNP)** はマウスレイヤー（精密モード）です。マウスの精密な操作が可能となり、右手側がマウスボタンになり、移動速度が減速します。右手最右列には各種トラックボール設定（スクロール反転、Auto Mouse Layer、CPI調整）キーが集約されています。
* **Layer 2 (Mouse / MSE)** もマウスレイヤーですが、精密モードではありません。通常のマウス操作が行えます。右手側がマウスボタンになります。右手最右列は透過（`&trans`）となっており、通常マウス操作中の意図しないキー誤入力を防止します。
* **Layer 3 (Scroll / SCR)** はスクロールレイヤーです。トラックボールを転がすと上下左右スクロール操作が可能となります（`&scrl_inv_tog` で上下反転可能）。
* **Layer 4** と **Layer 5** は予備レイヤーです。これらのレイヤーには任意のキーコードを設定することができます。ユーザーの好みに応じてカスタマイズが可能です。
* **Layer 6 (Auto Mouse / AML)** は自動マウスレイヤーです。トラックボールを操作すると自動的にこのレイヤーに切り替わり、マウスキー操作が可能になります。約5秒間操作がないと自動的に元のレイヤーに戻ります（`&aml_tog` で機能全体の有効/無効を切り替え可能）。

### トラックボール機能のリアルタイム制御 (Rev4 / Rev3)

Rev4 および Rev3 では、ソースコードを再ビルドすることなく、**キーボードのキー操作だけでリアルタイムにトラックボールの各種設定（CPI感度、Auto Mouse Layer、スクロール反転）を変更可能** です。

各種設定キーは、**レイヤー 1（精密モード）の右手最右列に縦一列で集約**されています。各設定値は Xiao BLE 内部の不揮発性メモリ（NVS）に自動保存されるため、キーボードの電源を切ったりバッテリーを交換しても前回の設定がそのまま維持されます。

> [!NOTE]
> 通常マウスモードである **レイヤー 2（MSE）** では、マウス操作中の意図しないキー誤入力を防止するため調整キーを配置せず、透過（`&trans`）としています。トラックボールの設定変更は **レイヤー 1（SNP）** から行います。

#### 右手最右列のキー配置比較

| 段 | レイヤー 1 (SNP: 精密モード) | レイヤー 2 (MSE: 通常マウスモード) | 機能・説明 |
| :--- | :--- | :--- | :--- |
| **ROW 1（最上段）** | `&studio_unlock` | `&kp F11` | ZMK Studio ロック解除 / ファンクションキー |
| **ROW 2** | **`&scrl_inv_tog`** | `&trans`（透過） | **スクロール反転切替**（通常 ⇔ 反転 / ナチュラルスクロール） |
| **ROW 3** | **`&aml_tog`** | `&trans`（透過） | **Auto Mouse Layer 切替**（自動レイヤー切り替え機能の ON ⇔ OFF） |
| **ROW 4** | **`&cpi_inc`** | `&trans`（透過） | **CPI 感度UP**（解像度を 1 段階上げる） |
| **ROW 5（最下段）** | **`&cpi_dec`** | `&trans`（透過） | **CPI 感度DOWN**（解像度を 1 段階下げる） |

#### 各制御キーの機能詳細

* **`&scrl_inv_tog`（スクロール反転切替）**:
  * レイヤー 3（スクロールモード）での**上下スクロール方向（通常 ⇔ 反転 / ナチュラルスクロール）**をリアルタイムにトグルします。
* **`&aml_tog`（Auto Mouse Layer ON/OFF切替）**:
  * トラックボール操作時にレイヤー 6（自動マウスレイヤー）へ自動遷移する機能の**有効 / 無効**をトグルします。OFF にするとボールを動かしてもレイヤーが切り替わらず、純粋なカーソル移動のみが行われます。
* **`&cpi_inc` / `&cpi_dec`（感度調整）**:
  * トラックボールの解像度（CPI）を 1 段階ずつリアルタイムに調整します。
  * **操作方法**: `&cpi_inc` キーで 1 ステップ増加（高速化）、`&cpi_dec` キーで 1 ステップ減少（低速化）。
  * **Rev4（PAW3222）の調整範囲（全16段階）**:
    `608` $\leftrightarrow$ `790` $\leftrightarrow$ `1003` $\leftrightarrow$ `1216` $\leftrightarrow$ `1428` $\leftrightarrow$ `1611` $\leftrightarrow$ `1824` $\leftrightarrow$ `2036` $\leftrightarrow$ `2249` $\leftrightarrow$ `2462` $\leftrightarrow$ `2827` $\leftrightarrow$ `3222` $\leftrightarrow$ `3617` $\leftrightarrow$ `4012` $\leftrightarrow$ `4408` $\leftrightarrow$ `4826` CPI
  * **Rev3（PMW3610）の調整範囲（全15段階）**:
    `200` $\leftrightarrow$ `400` $\leftrightarrow$ `600` $\leftrightarrow$ `800` $\leftrightarrow$ `1000` $\leftrightarrow$ `1200` $\leftrightarrow$ `1400` $\leftrightarrow$ `1600` $\leftrightarrow$ `1800` $\leftrightarrow$ `2000` $\leftrightarrow$ `2200` $\leftrightarrow$ `2400` $\leftrightarrow$ `2600` $\leftrightarrow$ `2800` $\leftrightarrow$ `3200` CPI
* **ドングル OLED 画面との連携**:
  * OLED ディスプレイ付きドングルを使用している場合、現在の CPI 値（例: `CPI:1600`）や、Automouse（`🎱(A)`）/ スクロール反転（`↕️`）アイコンの有効状態（下線表示）が画面上にリアルタイム連動します。

### トラックボール設定変更

トラックボールの設定を変更するには、リポジトリをフォークしてソースコードを修正する必要があります。

フォークとは、他のユーザーのリポジトリを自分のアカウントにコピーし、自由に変更を加えることができる機能です。

変更した設定をフォークしたリポジトリにコミットすると、GitHub Actionsにより自動的にファームウェアがビルドされます。
> [!NOTE]
> GitHub Actionsは、リポジトリに変更が加えられた際に自動的にビルドやテストを実行するCI/CDツールです。

ビルドされたファームウェアをダウンロードしてキーボードに書き込み、変更したトラックボール設定でキーボードを使用できます。

#### 自動マウスレイヤー（Layer 6）の設定変更

トラックボール操作時に自動的にマウスレイヤー（Layer 6）へ切り替わる動作は、`config/mtk64.keymap`（[Rev4版](https://github.com/mentako-ya/zmk-config-mtk64/blob/right_left_rev4/config/mtk64.keymap#L16-L18) / [Rev3版](https://github.com/mentako-ya/zmk-config-mtk64/blob/right_left_rev3/config/mtk64.keymap#L16-L18)）で設定されています。

```dts
&mkp_input_listener {
    input-processors = <&zip_temp_layer 6 5000>;
};
```

* **第1引数 (`6`)**: 自動遷移先のマウスレイヤー番号（デフォルトは Layer 6）。
* **第2引数 (`5000`)**: トラックボール操作を止めてから元のレイヤーに自動復帰するまでの時間（ミリ秒、`5000` = 5秒）。

また、キー入力後にトラックボールが反応するまでのアイドル時間などは、`config/boards/shields/mtk64/mtk64_trackball.dtsi`（[Rev4版](https://github.com/mentako-ya/zmk-config-mtk64/blob/right_left_rev4/config/boards/shields/mtk64/mtk64_trackball.dtsi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) / [Rev3版](https://github.com/mentako-ya/zmk-config-mtk64/blob/right_left_rev3/config/boards/shields/mtk64/mtk64_trackball.dtsi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)）で調整可能です：

```dts
zip_temp_layer: zip_temp_layer {
    compatible = "zmk,input-processor-temp-layer";
    #input-processor-cells = <2>;
    require-prior-idle-ms = <500>;
    excluded-positions = <43 44 45 46 47>; // MB4, MB5, MB1, MB2, MB3
};
```

* `require-prior-idle-ms = <500>;`: タイピング中の誤爆を防ぐため、キー入力後 500ms 経過してからトラックボールを操作した際に自動レイヤー切り替えが発動します。
* `excluded-positions`: マウスボタン（MB1〜MB5）を押した際にタイマーがリセットされる除外キー位置です。

#### トラックボール感度（CPI）の初期値調整

通常はキーボード右下の **`cpi_inc`** / **`cpi_dec`** キーでリアルタイム調整可能ですが、ファームウェア起動時のデフォルト初期値を変更したい場合は、各ブランチの `config/boards/shields/mtk64/mtk64_trackball.dtsi` 内の `res-cpi` を編集します：

* **Rev4（PAW3222）**: [`mtk64_trackball.dtsi (right_left_rev4)`](https://github.com/mentako-ya/zmk-config-mtk64/blob/right_left_rev4/config/boards/shields/mtk64/mtk64_trackball.dtsi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)
  ```dts
  trackball: trackball@0 {
      compatible = "pixart,paw32xx";
      ...
      res-cpi = <1558>; /* デフォルト初期CPI (16段階) */
  };
  ```

* **Rev3（PMW3610）**: [`mtk64_trackball.dtsi (right_left_rev3)`](https://github.com/mentako-ya/zmk-config-mtk64/blob/right_left_rev3/config/boards/shields/mtk64/mtk64_trackball.dtsi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)
  ```dts
  trackball: trackball@0 {
      compatible = "pixart,pmw3610";
      ...
      res-cpi = <1000>; /* デフォルト初期CPI (15段階) */
  };
  ```

## ケースデータ

[ケースデータ ダウンロード](casedata/)

[mtk64ebt rev1ケース](https://github.com/mentako-ya/mtk64ebt/tree/main/casedata/rev1)

[mtk64ebt rev2ケース](https://github.com/mentako-ya/mtk64ebt/tree/main/casedata/rev2)

[mtk64ebt rev3ケース](https://github.com/mentako-ya/mtk64ebt/tree/main/casedata/rev3)

[mtk64ebt rev4ケース](https://github.com/mentako-ya/mtk64ebt/tree/main/casedata/rev4)

[XiaoBleドングルケース](https://github.com/mentako-ya/mtk64ebt/blob/main/casedata/XiaoBle/XiaoBleDongle.3mf)

[XiaoBleドングル+OLEDケース](https://github.com/mentako-ya/mtk64ebt/blob/main/casedata/XiaoBleDongleOLED/XiaoBleDongleOLED.3mf)

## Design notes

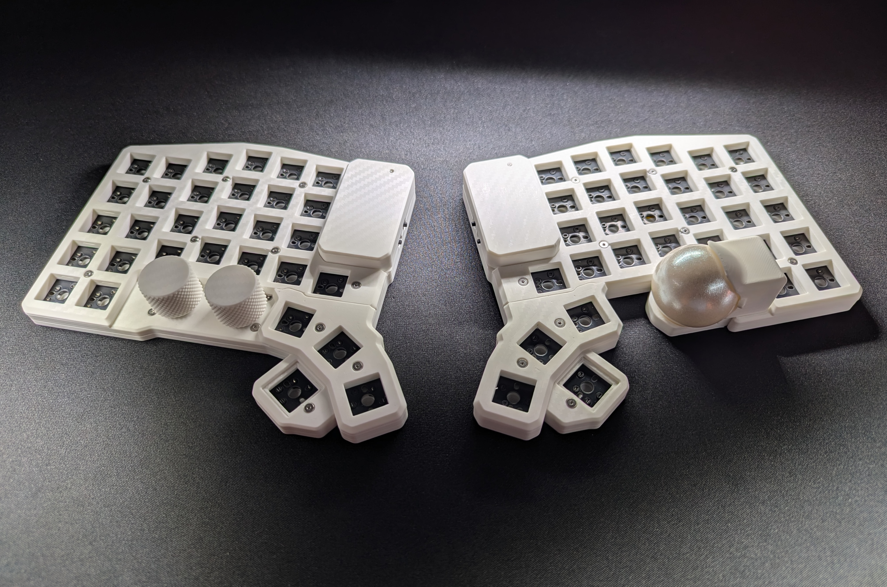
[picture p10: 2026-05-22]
image/rev3/mtk64wbt_rev3_white.jpg

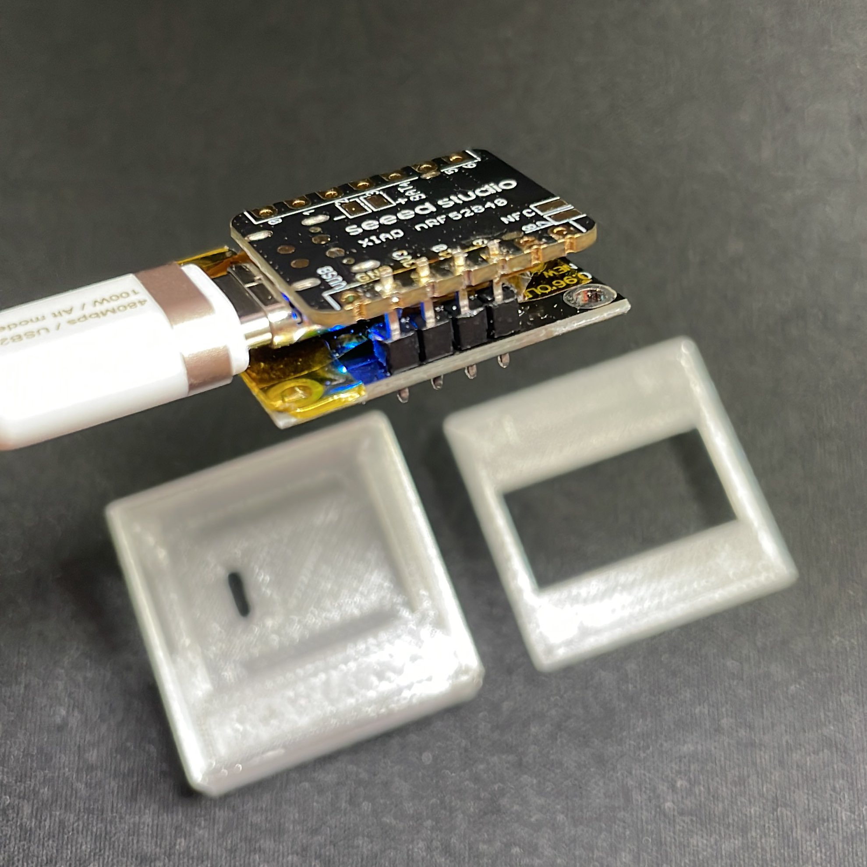
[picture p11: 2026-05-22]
image/DONGLE/DONGLE_OLED_3.jpeg

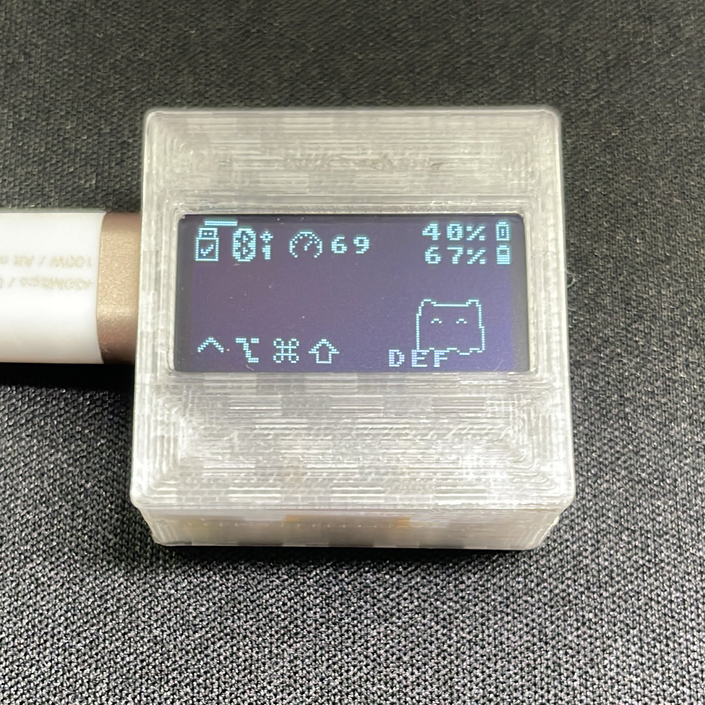
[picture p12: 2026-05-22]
image/DONGLE/DONGLE_OLED_1.jpeg

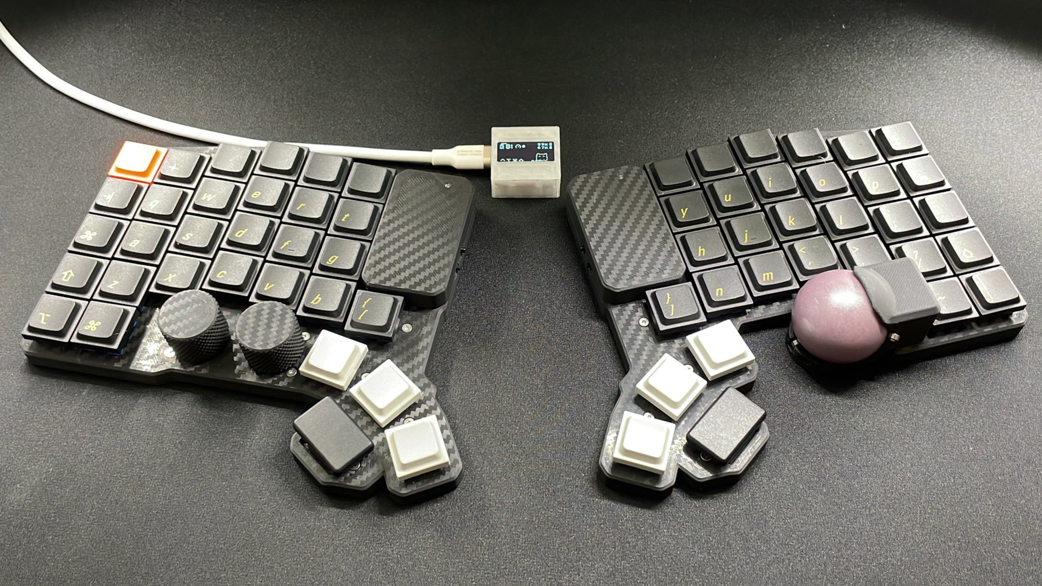
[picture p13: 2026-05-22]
image/DONGLE/DONGLE_OLED_4.jpeg

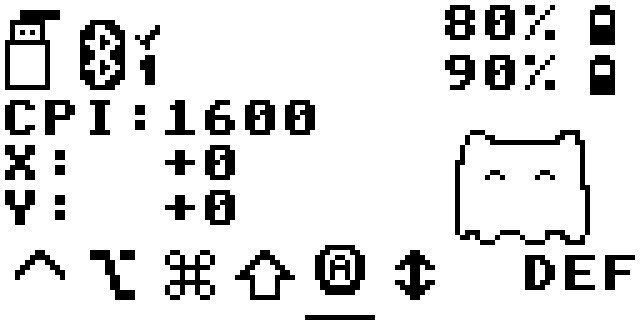
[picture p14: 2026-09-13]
image/DONGLE/oled_display_layout.png

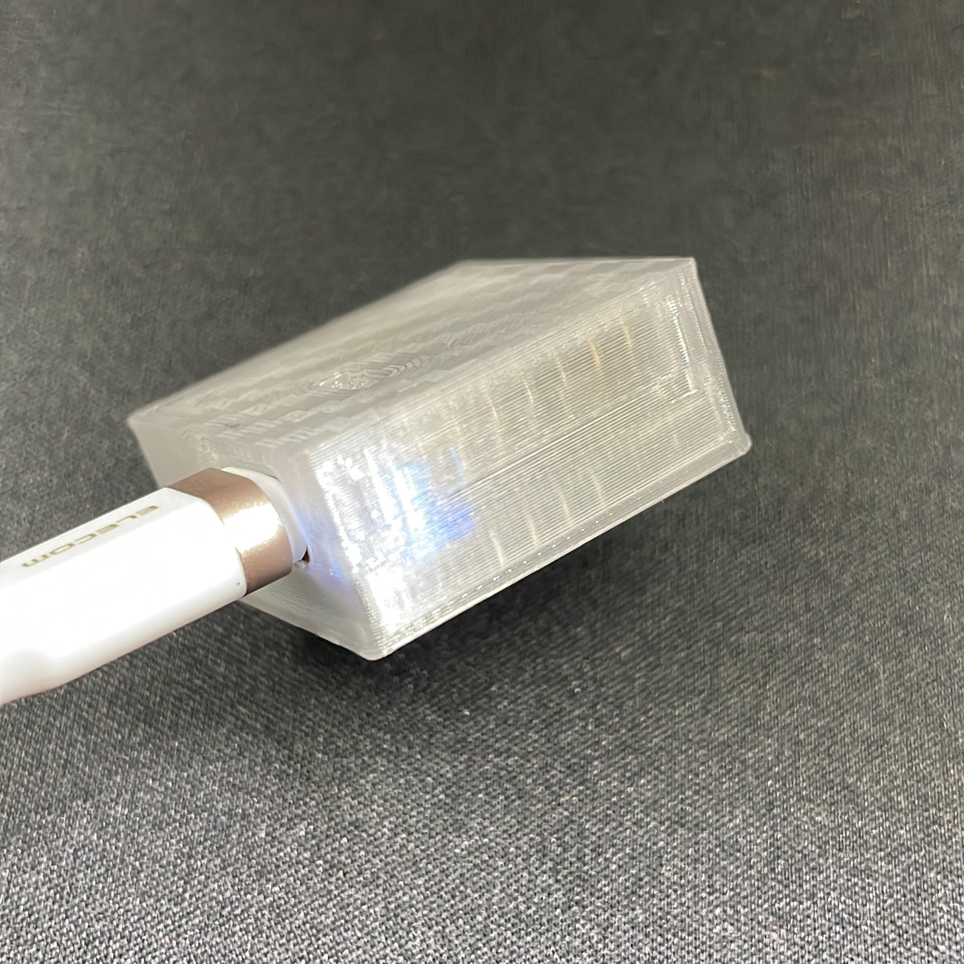
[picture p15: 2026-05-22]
image/DONGLE/DONGLE_OLED_2.jpeg

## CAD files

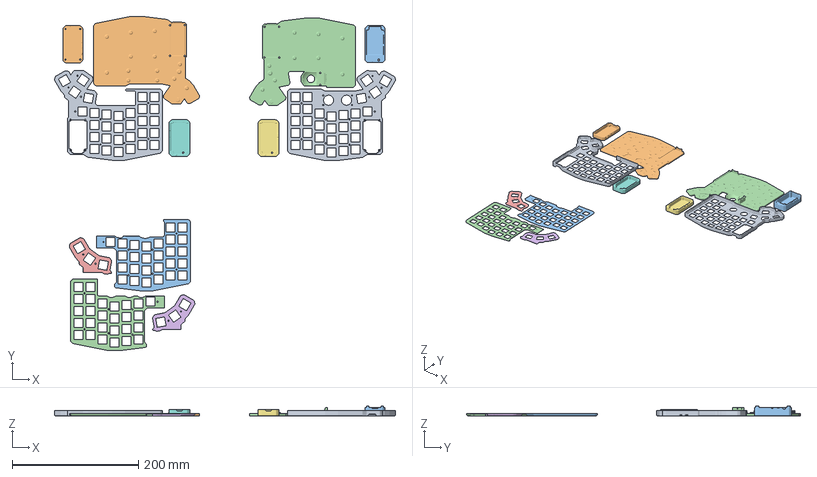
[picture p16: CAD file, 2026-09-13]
casedata/rev4/mtk64ebt_rev4_StanderdParts.3mf
540.9 x 529.9 x 15.4 mm
Body_enc
Body_enc_bottom
top_plate_ball_body_RH
top_plate_enc_body
top_plate_ball_thumb_LH
top_plate_enc_thumb
Body_mcu_LH
Body_mcu_RH
Body_ball_RH
fm_lower
fm_upper
BallCaseLower_RH

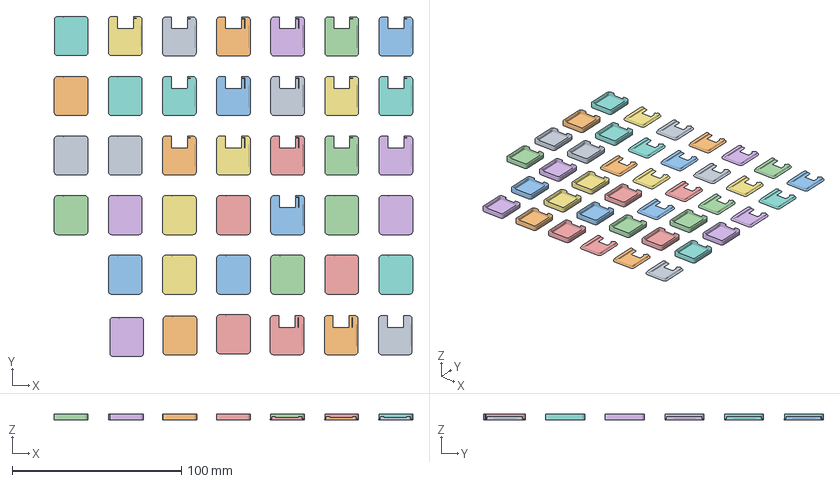
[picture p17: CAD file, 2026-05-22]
casedata/XiaoBle/XiaoBleDongle.3mf
212.0 x 201.0 x 3.50 mm
upper x 20
lower x 20

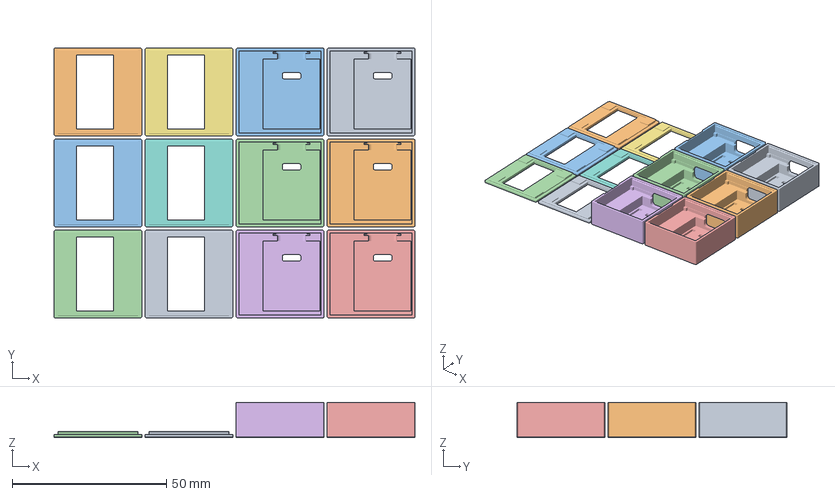
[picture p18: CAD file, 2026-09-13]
casedata/XiaoBleDongleOLED/XiaoBleDongleOLED.3mf
117.0 x 87.5 x 11.5 mm
Back x 6
Top x 6

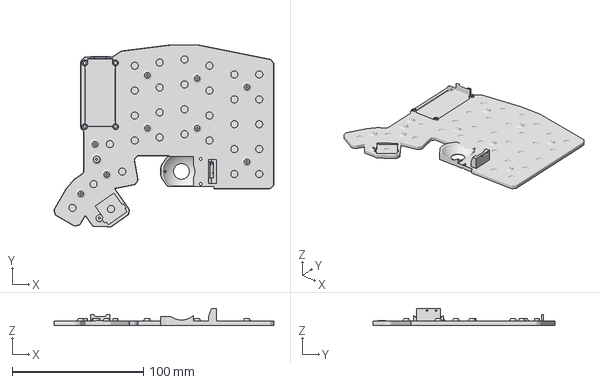
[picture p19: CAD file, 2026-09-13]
casedata/rev4/mtk64ebt_rev4_bodyBallBottmn_RH.3mf
167.9 x 139.2 x 13.0 mm

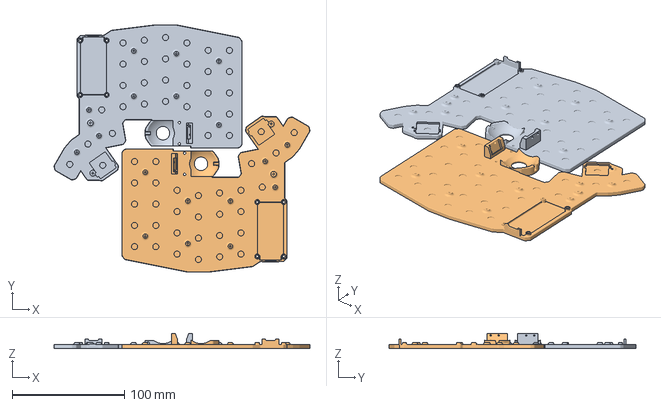
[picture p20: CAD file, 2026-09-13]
casedata/rev4/mtk64ebt_rev4_bodyBallBeringBottmn_RH.3mf
228.5 x 220.6 x 13.0 mm
BallCaseLower_RH x 2

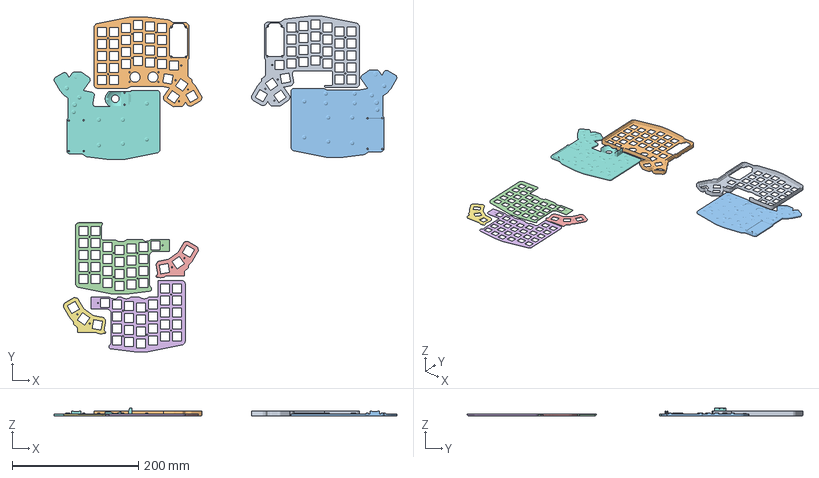
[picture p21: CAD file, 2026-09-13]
casedata/rev4/mtk64ebt_rev4_LeftBallParts.3mf
544.1 x 532.5 x 13.0 mm
Body_ball
Body_enc_RH
Body_enc_bottom_RH
top_plate_ball_body
top_plate_ball_thumb
top_plate_enc_body_RH
top_plate_enc_thumb_RH
BallBearingCaseLowerLH

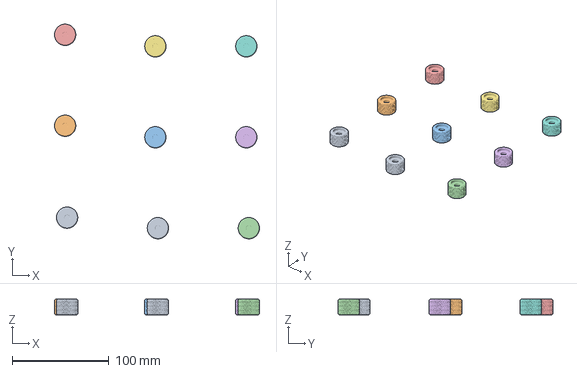
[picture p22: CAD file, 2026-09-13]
casedata/rev4/mtk64ebt_rev4_encoder_knob.3mf
211.6 x 221.6 x 16.0 mm
KanbA x 9

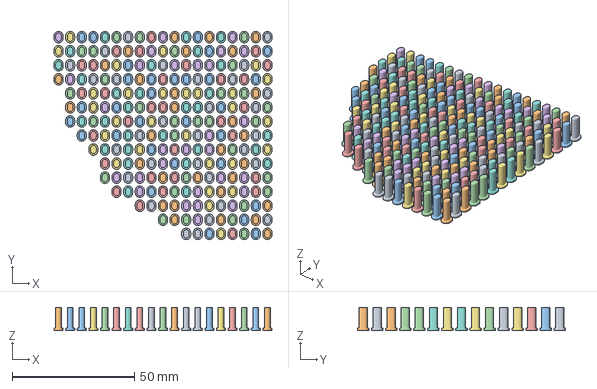
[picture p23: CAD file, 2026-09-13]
casedata/rev4/mtk64ebt_rev4_footmodule_lens.3mf
89.2 x 85.2 x 9.50 mm
fm_lens x 237

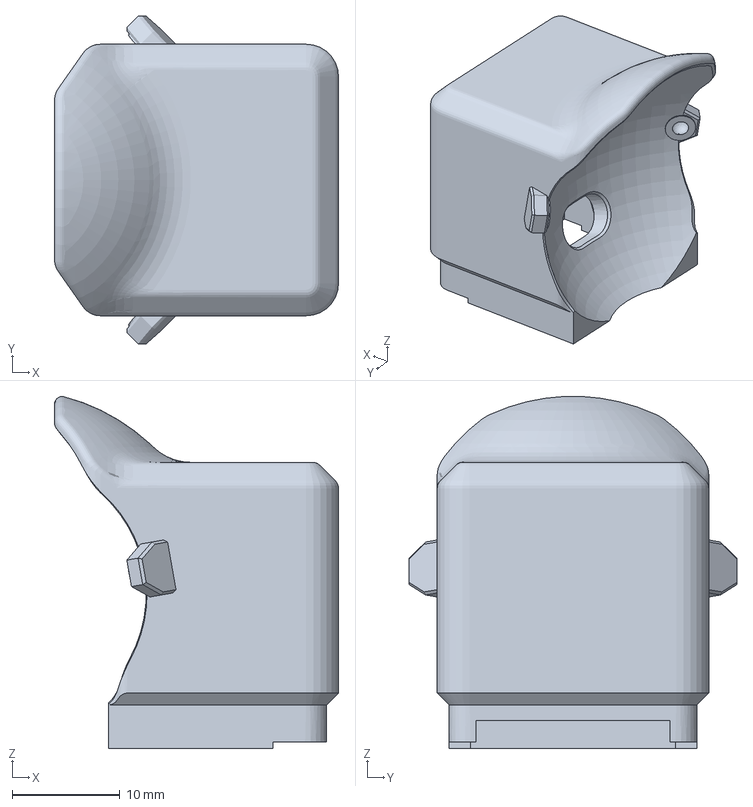
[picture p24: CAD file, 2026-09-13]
casedata/rev4/mtk64ebt_rev4_ballCase.3mf
26.4 x 30.5 x 32.7 mm

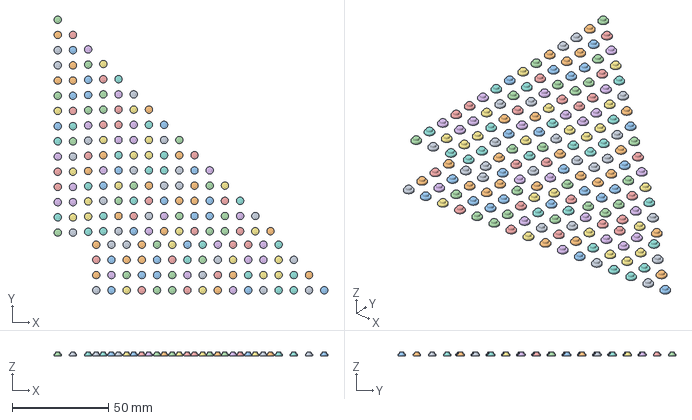
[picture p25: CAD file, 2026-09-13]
casedata/rev4/mtk64ebt_rev4_LED_lens.3mf
142.4 x 144.5 x 2.00 mm
LED_lens x 178

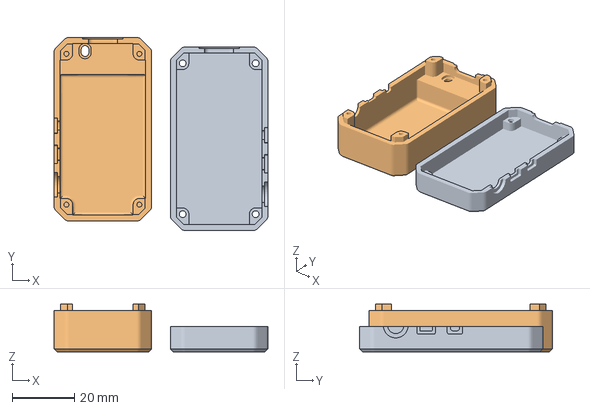
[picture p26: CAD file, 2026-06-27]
casedata/rev4/mtk64ebt_rev4_footmodule_case.3mf
69.0 x 62.3 x 15.4 mm
fm_lower
fm_upper

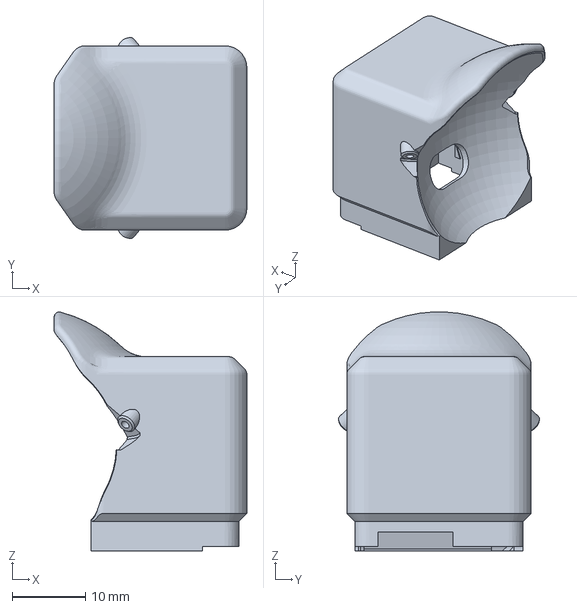
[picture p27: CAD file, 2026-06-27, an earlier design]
casedata/rev3/mtk64ebt_rev3_ballBearingCase_RH.3mf
26.4 x 27.5 x 32.7 mm

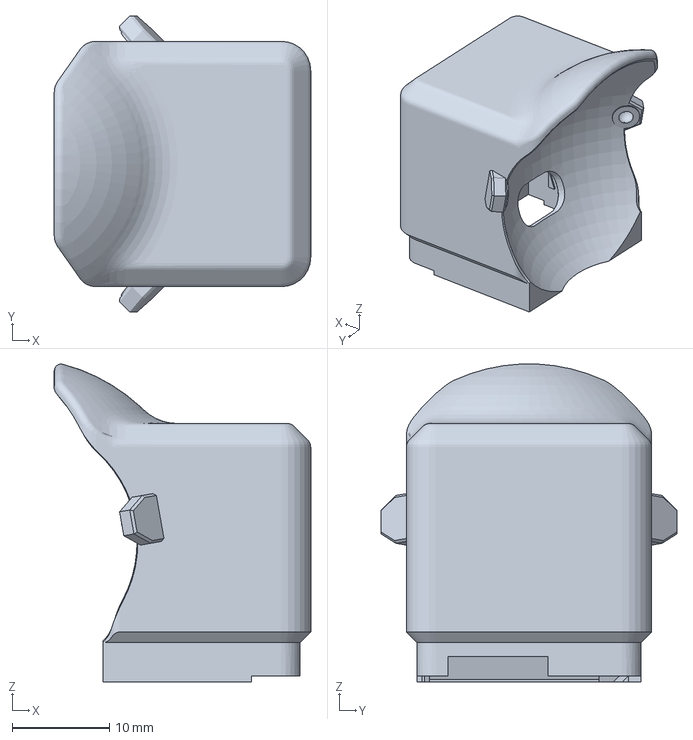
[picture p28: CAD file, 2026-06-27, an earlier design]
casedata/rev3/mtk64ebt_rev3_ballCase_RH.3mf
26.4 x 30.5 x 32.7 mm

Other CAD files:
casedata/rev4/mtk64ebt_rev4_bodyBallBottmn_LH.3mf
casedata/rev3/mtk64ebt_rev3_footmodule_lens.3mf
casedata/rev3/mtk64ebt_rev3_LED_lens.3mf
casedata/rev3/mtk64ebt_rev3_LeftBallParts.3mf

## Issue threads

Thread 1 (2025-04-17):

ファームウェア書き込み後に左デバイスから入力できなくなる

txkxyx-okkan, 2025-04-17:
[ファームウェア書き込み手順](https://github.com/mentako-ya/mtk64ebt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)に従い初めての書き込み後に左デバイスからキーボード入力できなくなりました。右デバイスは入力できています。

左デバイスのファームウェア書き込み後にリセットボタンを押した際のLEDは、🟡 🔴の順で点灯します。

商品到着2日目で、昨日は特に問題なく動いておりました。原因の特定や復旧方法があれば教えてください。

**使用環境**
- フォークしたリポジトリ
  - https://github.com/txkxyx-okkan/zmk-config-mtk64
- PC
  - Mac Book Pro M2 Max
- Keymap Editorでwarningは出ています

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

mentako-ya, 2025-04-18:
> 左デバイスのファームウェア書き込み後にリセットボタンを押した際のLEDは、🟡 🔴の順で点灯します。

LEDの点灯の意味は[こちら](https://github.com/mentako-ya/zmk-rgbled-widget/blob/main/README.md)の記載通りです。
最初の🟡はバッテリーレベルが中程度であることを示します。
次の🔴はスプリットの周辺側（左手側）がセントラル側（右手側）とペアリングされていないことを示します。

ファームウェアの書き換え前にリセット用ファームウェアを書き込まなかった場合、左右間のペアリングに失敗します。
また、右手の電源が入っていない場合、右手側のファームウェアがリセットされていない場合も左右間のペアリングに失敗します。**リセット用ファームウェアは両側に書き込んでください。**

こちらでビルドしたファームウェア[mtk64ebt_Right_Left.zip](https://github.com/mentako-ya/mtk64ebt/blob/main/firmware/mtk64ebt_Right_Left.zip)を解凍してください。
**settings_reset-seeeduino_xiao_ble-zmk.uf2を左右両方に書き込んだのち**
右手側にmtk64_R rgbled_adapter-seeeduino_xiao_ble-zmk.uf2
左手側にmtk64_L rgbled_adapter-seeeduino_xiao_ble-zmk.uf2
を書き込んでください。

ご自身でビルドしたファームウェアを使用した場合、こちらで問題の診断はできません。

リセット用ファームウェアの詳細はZMKのドキュメントを参照してください。
https://zmk.dev/docs/troubleshooting/connection-issues#reset-split-keyboard-procedure

mentako-ya, 2025-04-22:
こちらの事象ですが解消しましたでしょうか。
解消しない場合、左手側に一度右手用のファームウエア（セントラル側のファームウェア）を書き込んで有線接続で動作を確認していただけますでしょうか。
（セントラル側のファームウェアを書き込むと左手側でも有線接続できますが、キーマップは出鱈目になるので、あくまで動作確認用です）
右手側のファームウエアで左手側の動作確認ができたら、リセット用ファームウエアを左右に書き込んだのちに、正しいファームウェアを書き込んでみてください。

txkxyx-okkan, 2025-04-23:
回答遅くなりました。
同じ部品を利用しているであろう、roBaのビルドガイドのファームウェア書き込み手順を参考に作業すると解決できました。
https://github.com/kumamuk-git/roBa/blob/main/doc/v2/buildguide_v2.md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

差分としては、ファームウェアを書き込む際は電源をオフにする、ぐらいだと思います。
キーボードとPCの接続も有線での接続と、Bluetoothを利用して無線での接続のどちらもできました。

mentako-ya, 2025-04-23:
> ファームウェアを書き込む際は電源をオフにする
こちらを手順に加えさせていただきます。
ご報告ありがとうございました。

Closed 2025-04-23.

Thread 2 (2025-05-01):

ZMK で mouse_move の設定ができない

masaru-suzuki, 2025-05-01:
- ZMK Studio (Web版・アプリ版)
- Behavior を `mouse_key_press` から別の Behavior に変更した

その後、`mouse_key_press` を選択しても保存ボタンが有効にならず、元に戻せなくなる。

ZMK の問題かもしれないのですが、一旦 issue であげさせてもらいました。

masaru-suzuki, 2025-05-01:
https://github.com/user-attachments/assets/023fd882-8a01-402c-be71-c900b24e821f

mentako-ya, 2025-05-03:
zmk studioの動作について一般的なバグであればこちらにお願いいたします
https://github.com/zmkfirmware/zmk-studio/issues

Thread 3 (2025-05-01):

設定項目が何を指すか読み取れない

masaru-suzuki, 2025-05-01:
READMEにありました、👇の項目について、それぞれの変数が何を指すのか教えていただきたいです！

```
    CONFIG_PMW3610=y
    CONFIG_PMW3610_CPI=1000
    CONFIG_PMW3610_CPI_DIVIDOR=1
    CONFIG_PMW3610_ORIENTATION_90=y
    CONFIG_PMW3610_SNIPE_CPI=800
    CONFIG_PMW3610_SNIPE_CPI_DIVIDOR=4
    CONFIG_PMW3610_SCROLL_TICK=16
    CONFIG_PMW3610_INVERT_X=y
    CONFIG_PMW3610_INVERT_SCROLL_X=n
    CONFIG_PMW3610_RUN_DOWNSHIFT_TIME_MS=3264
    CONFIG_PMW3610_POLLING_RATE_250=y
    CONFIG_PMW3610_AUTOMOUSE_TIMEOUT_MS=700
    CONFIG_PMW3610_AUTOMOUSE_THRESHOLD=10
    CONFIG_PMW3610_SMART_ALGORITHM=y
```

mentako-ya, 2025-05-03:
CONFIG_PMW3610_xxxxについてはソースコードに概要のコメント、デフォルト値、範囲など記載されているので参照してください。
https://github.com/mentako-ya/zmk-pmw3610-driver/blob/main/Kconfig

mtk64erp（QMKファームウエア）と同様のカスタムキーコードによる設定変更ですが、ZMKで同様のことを実現している実装例が見当たりません
ZMKでカスタムのビヘイビアやマクロを使用してドライバーの設定変更を行なっている例があればご紹介いただきたいです

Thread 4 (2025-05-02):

ロータリーエンコーダーで Mouse scroll が選択できない

masaru-suzuki, 2025-05-02:
表題の通り、keymap Editor を利用して、ロータリーエンコーダーに @msc Mouse scroll を選択したいが、候補に出てこないため選択できない。

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

mentako-ya, 2025-05-03:
ZMKの仕様でマウススクロールの機能はエンコーダーに直接マッピングできません。（マッピングしても機能しない）
エンコーダー用のマウススクロールのビヘイビアを自分で定義してエンコーダーにマッピングする必要があるようです。

垂直スクロール（scroll_up_down）,水平スクロール（scroll_left_right）ビヘイビアの定義とレイヤー３のエンコーダーへのマッピングのプルリクエストを作成しました
https://github.com/mentako-ya/zmk-config-mtk64/pull/1

ビルドしたファームウェアをこちらからダウンロードして試してください。
https://github.com/mentako-ya/zmk-config-mtk64/actions/runs/14806760745/artifacts/3054400700

masaru-suzuki, 2025-05-03:
PRの作成ありがとうございます！
差分を取り込んだところ、縦横のスクロールが可能になりました！ 👍

masaru-suzuki, 2025-05-03:
解決したためクローズします！
迅速な対応ありがとうございます！

Closed 2025-05-03.

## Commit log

2025-10-13 Dongle disolay ファームウェア他
2025-11-03 左ボール右エンコーダー作例
    [mtk64ebt_rev3_LeftBallParts.3mf]
2025-11-03 README更新
2025-11-08 ファームウェア再アップロード
2025-11-16 左右＋ドングルモジュールOLED＋フットスイッチ無線化モジュール
2025-12-26 ファームウェア更新 zmk main (Zepher4.1) 対応
2025-12-27 ケースデータリンク更新
2025-12-27 ファームウェア更新 zmk main (zephyr4.1) + zmk-dongle-display(zephyr4.1)対応
2026-01-11 ファームウェア更新 zmk main (zephyr4.1) + zmk-dongle-display(zephyr4.1)対応 キーマップ修正
2026-03-14 ファームウェア更新 zmk main (zephyr4.1) add zmk variant dts
2026-04-05 ファームウェアの更新とブランチ名の修正、不要なファイルの削除
2026-04-07 LeftBallParts fix leyout
    [mtk64ebt_rev3_LeftBallParts.3mf]
2026-05-22 Update case 3D model files for XiaoBle
    [XiaoBleDongle.3mf, XiaoBleDongleOLED.3mf]
2026-05-22 buildgide/mtk64ebt_build00_ケースプリント.mov削除
2026-06-27 Move footswitch_kit images to image/ and update README links
    [mtk64ebt_rev3_ballBearingCase_RH.3mf, mtk64ebt_rev3_ballCase_RH.3mf, mtk64ebt_rev3_footmodule_case.3mf]
2026-09-13 feat(rev4): mtk64ebt Rev4 への全面アップデート（ケースデータ、1000Hz ESBファームウェア、機能解説）
    - Rev4 3Dプリント用ケースデータ（3MF）の追加
    - PAW3222センサー採用および1000Hz ESB対応のRev4用ビルド済みファームウェアパッケージ一式を追加
    - README.md のRev4全面アップデート（機能概要、各接続モードの実測ポーリングレート・計測ツール、ディスプレイ仕様等）
    [XiaoBleDongleOLED.3mf, mtk64ebt_rev3_LED_lens.3mf, mtk64ebt_rev3_footmodule_lens.3mf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]
2026-09-23 Rev3 記載修正
2026-10-21 ballCase印刷方向変更
